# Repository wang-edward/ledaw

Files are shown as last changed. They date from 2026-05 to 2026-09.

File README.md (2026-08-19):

# ledaw

run desktop app
```sh
cargo run
```

build
```sh
cargo build
```

build firmware
```sh
cargo build -p firmware
```

test
```sh
cargo test
```

lint + format
```sh
# rustup component add clippy rustfmt  # if you don't have it
cargo clippy --all-targets --all-features
cargo fmt --check
```

## Firmware

see [`firmware/README.md`](firmware/README.md) for flashing the rp2350.

## pics
Screenshot 2026-03-18 at 12 51 28 AM
Screenshot 2026-03-18 at 12 51 50 AM
Screenshot 2026-03-18 at 12 52 29 AM

## Video demo
video demo (https://www.youtube.com/watch?v=XMdhAa6qCPk)

## Video demo 2 (art project)
art demo (https://www.youtube.com/watch?v=T37_Ot39h1g)

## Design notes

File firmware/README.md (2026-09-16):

## Prerequisites
Install the embedded Rust target:
```sh
rustup target add thumbv8m.main-none-eabihf
```

Install [cargo-embed](https://probe.rs/docs/tools/cargo-embed/):
```sh
cargo install cargo-embed
```

Load the Raspberry Pi Debug Probe firmware onto the RP2040. (MacOS)
```sh
cp probe/debugprobe_on_pico.uf2 /Volumes/RPI-RP2/
```

Connect the RP2040 to the computer over USB and connect its SWD pins to the RP2350:
```text
RP2040 GP2 -> RP2350 SWCLK
RP2040 GP3 -> RP2350 SWDIO
RP2040 GND -> carrier GND
```

## Build
Run this from the `firmware` directory so Cargo loads its embedded target and runner configuration:
```sh
cargo build
```

Flash And Run Over SWD
```sh
cargo embed
```

Check Probe Connection
```sh
probe-rs list
probe-rs info --chip RP235x --protocol swd
```

Examples
```
cargo embed --example uart_echo
cargo embed --example midi_loopback
cargo joystick
```

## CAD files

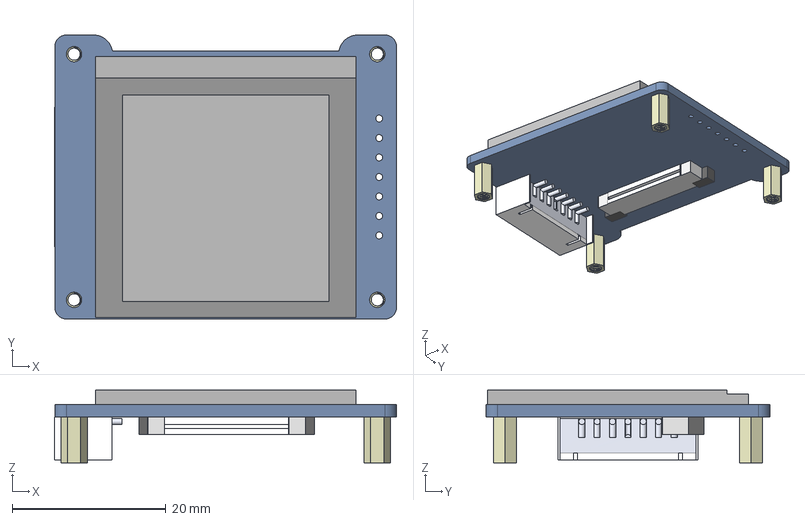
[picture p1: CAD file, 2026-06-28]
hardware/board/3d/1_5inch-rgb-oled-module_asm-1110.stp
44.5 x 37.0 x 9.50 mm
1_5INCH-RGB-OLED
1_5INCH_OLED_RGB_PCBA
M2XH6_COPPER-POST x 4

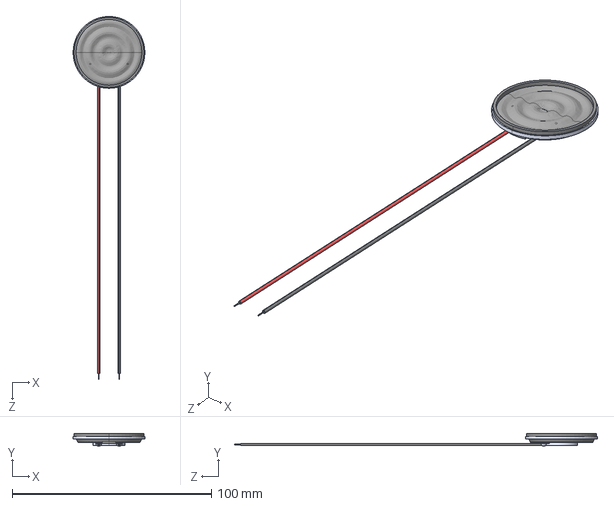
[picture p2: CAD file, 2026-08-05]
hardware/board/3d/Same_Sky_CLS0361-L152.step
36.0 x 6.30 x 182.0 mm

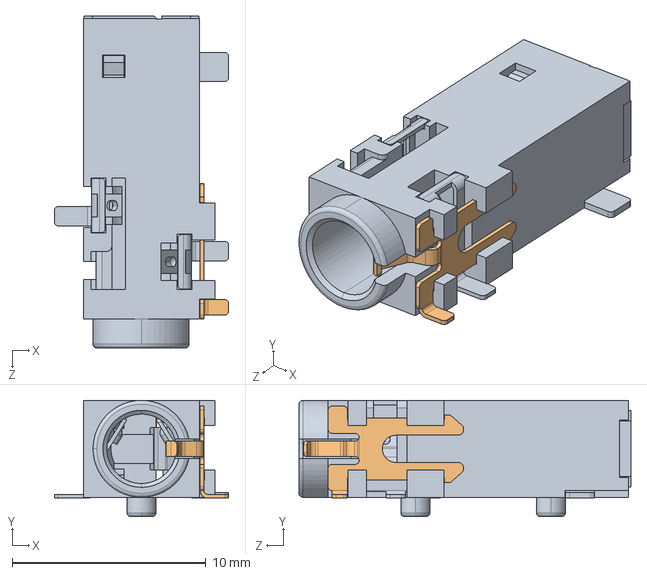
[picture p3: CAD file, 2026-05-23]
hardware/hat/3d/SJ-43514-SMT-TR.step
9.00 x 6.00 x 17.1 mm

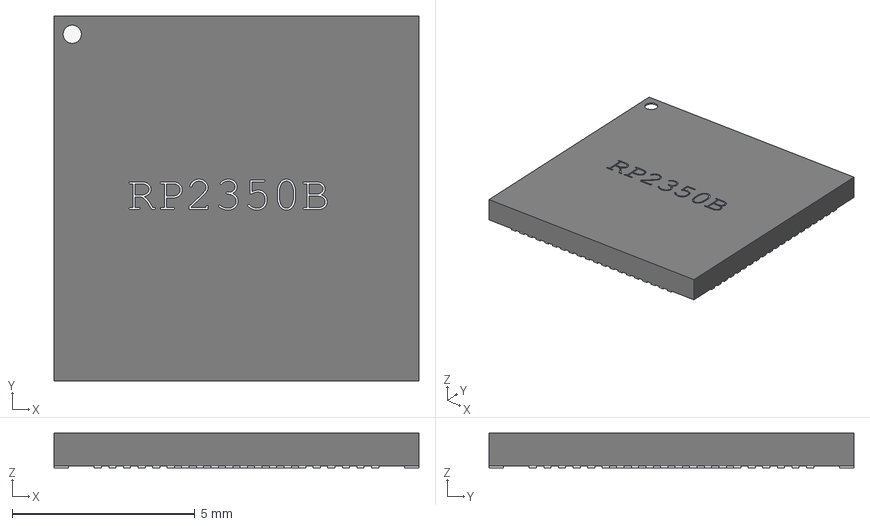
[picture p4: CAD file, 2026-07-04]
hardware/RP2350_80QFN_minimal/RP2350_QFN80.step
10.0 x 10.0 x 0.95 mm

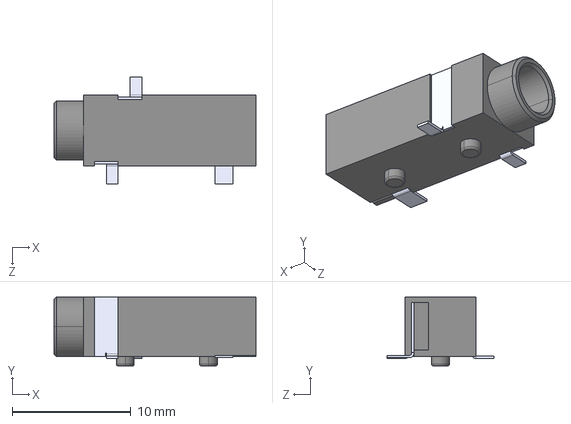
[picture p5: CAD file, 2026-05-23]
hardware/hat/3d/SJ-3523-SMT-TR.step
17.0 x 5.80 x 9.00 mm

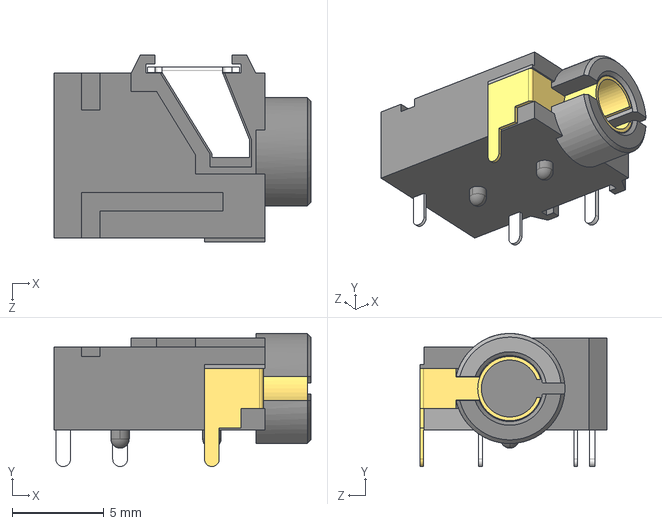
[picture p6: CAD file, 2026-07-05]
hardware/board/3d/SJ-43514.step
14.0 x 7.25 x 10.2 mm

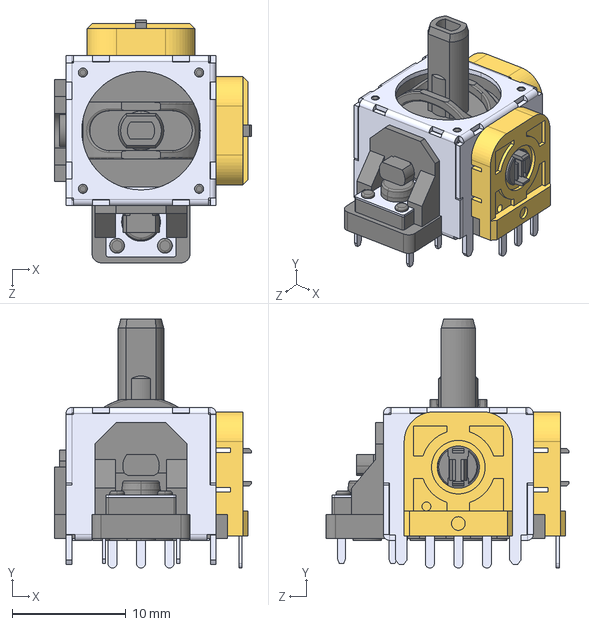
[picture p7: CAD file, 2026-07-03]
hardware/board/3d/THB001P.STEP
17.3 x 21.9 x 21.3 mm

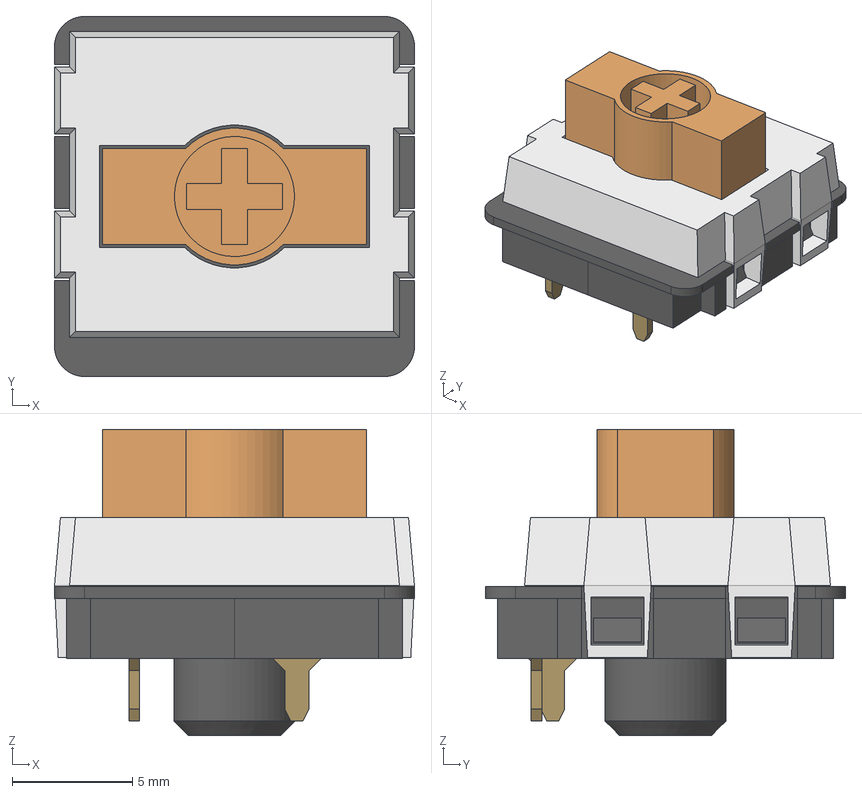
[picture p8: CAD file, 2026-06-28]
hardware/board/3d/Gateron KS-33.step
15.0 x 15.0 x 12.8 mm
Base
Stem
Cap
PinA
PinB

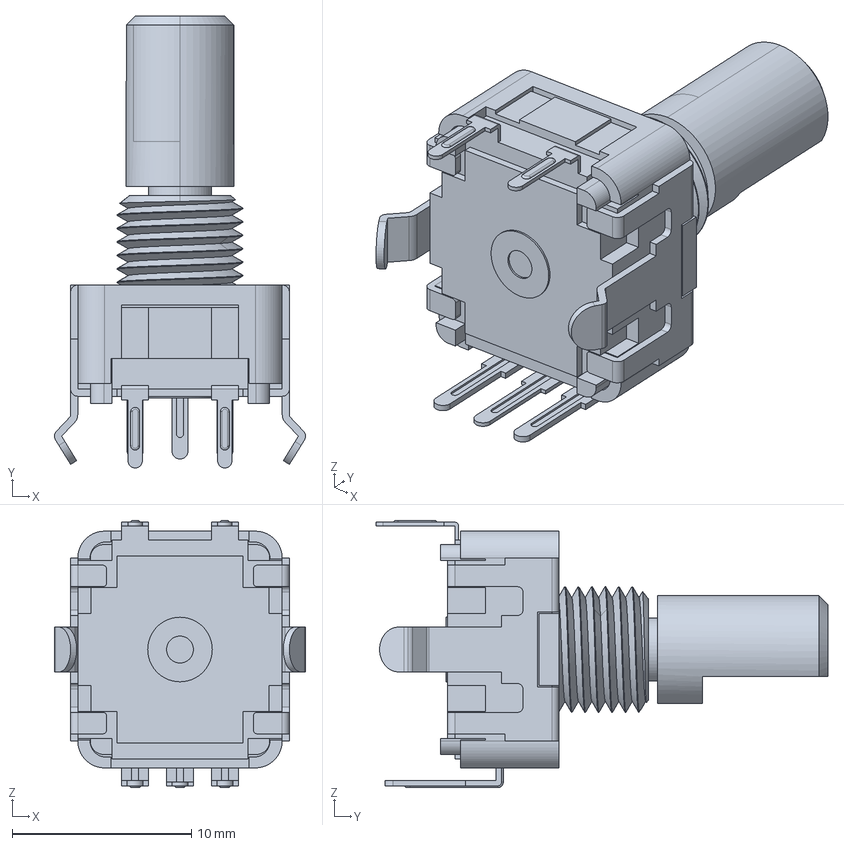
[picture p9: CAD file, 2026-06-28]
hardware/board/3d/pec11r-4015f-s0024.stp
14.0 x 25.2 x 14.9 mm

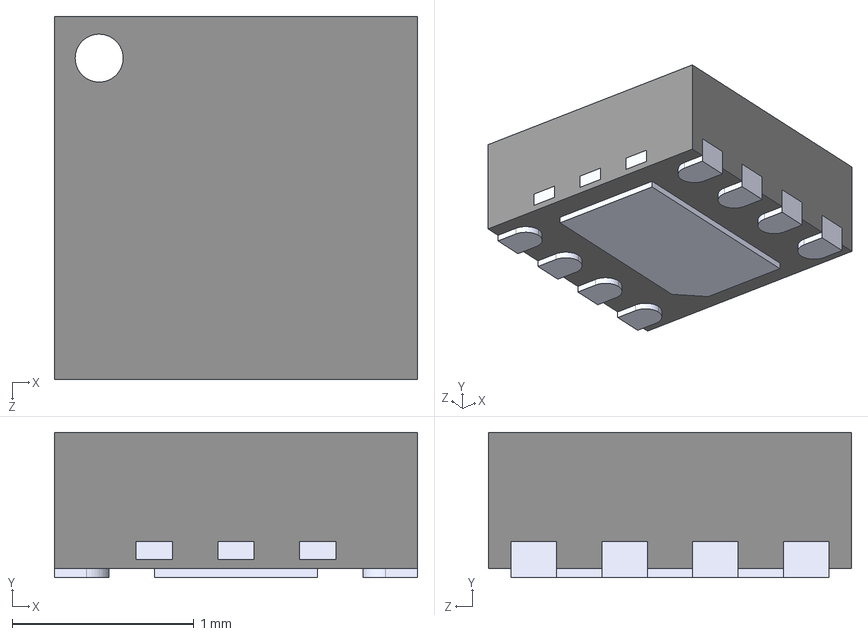
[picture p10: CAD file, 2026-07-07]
hardware/board/3d/TPS259531DSGR.step
2.00 x 0.8 x 2.00 mm

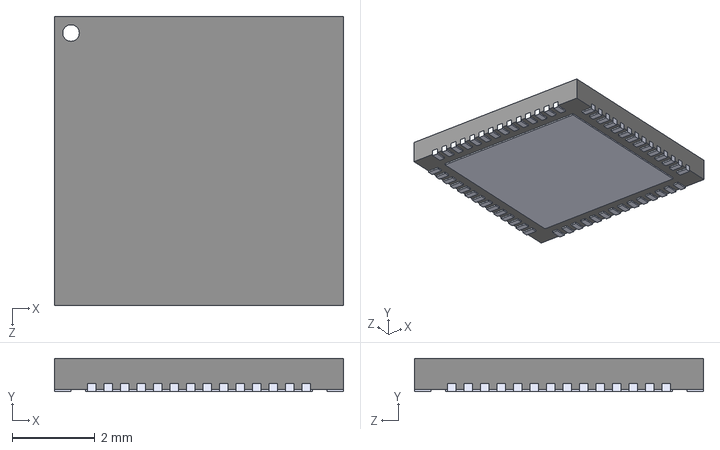
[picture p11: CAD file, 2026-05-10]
hardware/hat/3d/MAX98089ETN_T.step
7.00 x 0.8 x 7.00 mm

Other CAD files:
hardware/board/3d/Same_Sky_CLS0361-L152.x_t

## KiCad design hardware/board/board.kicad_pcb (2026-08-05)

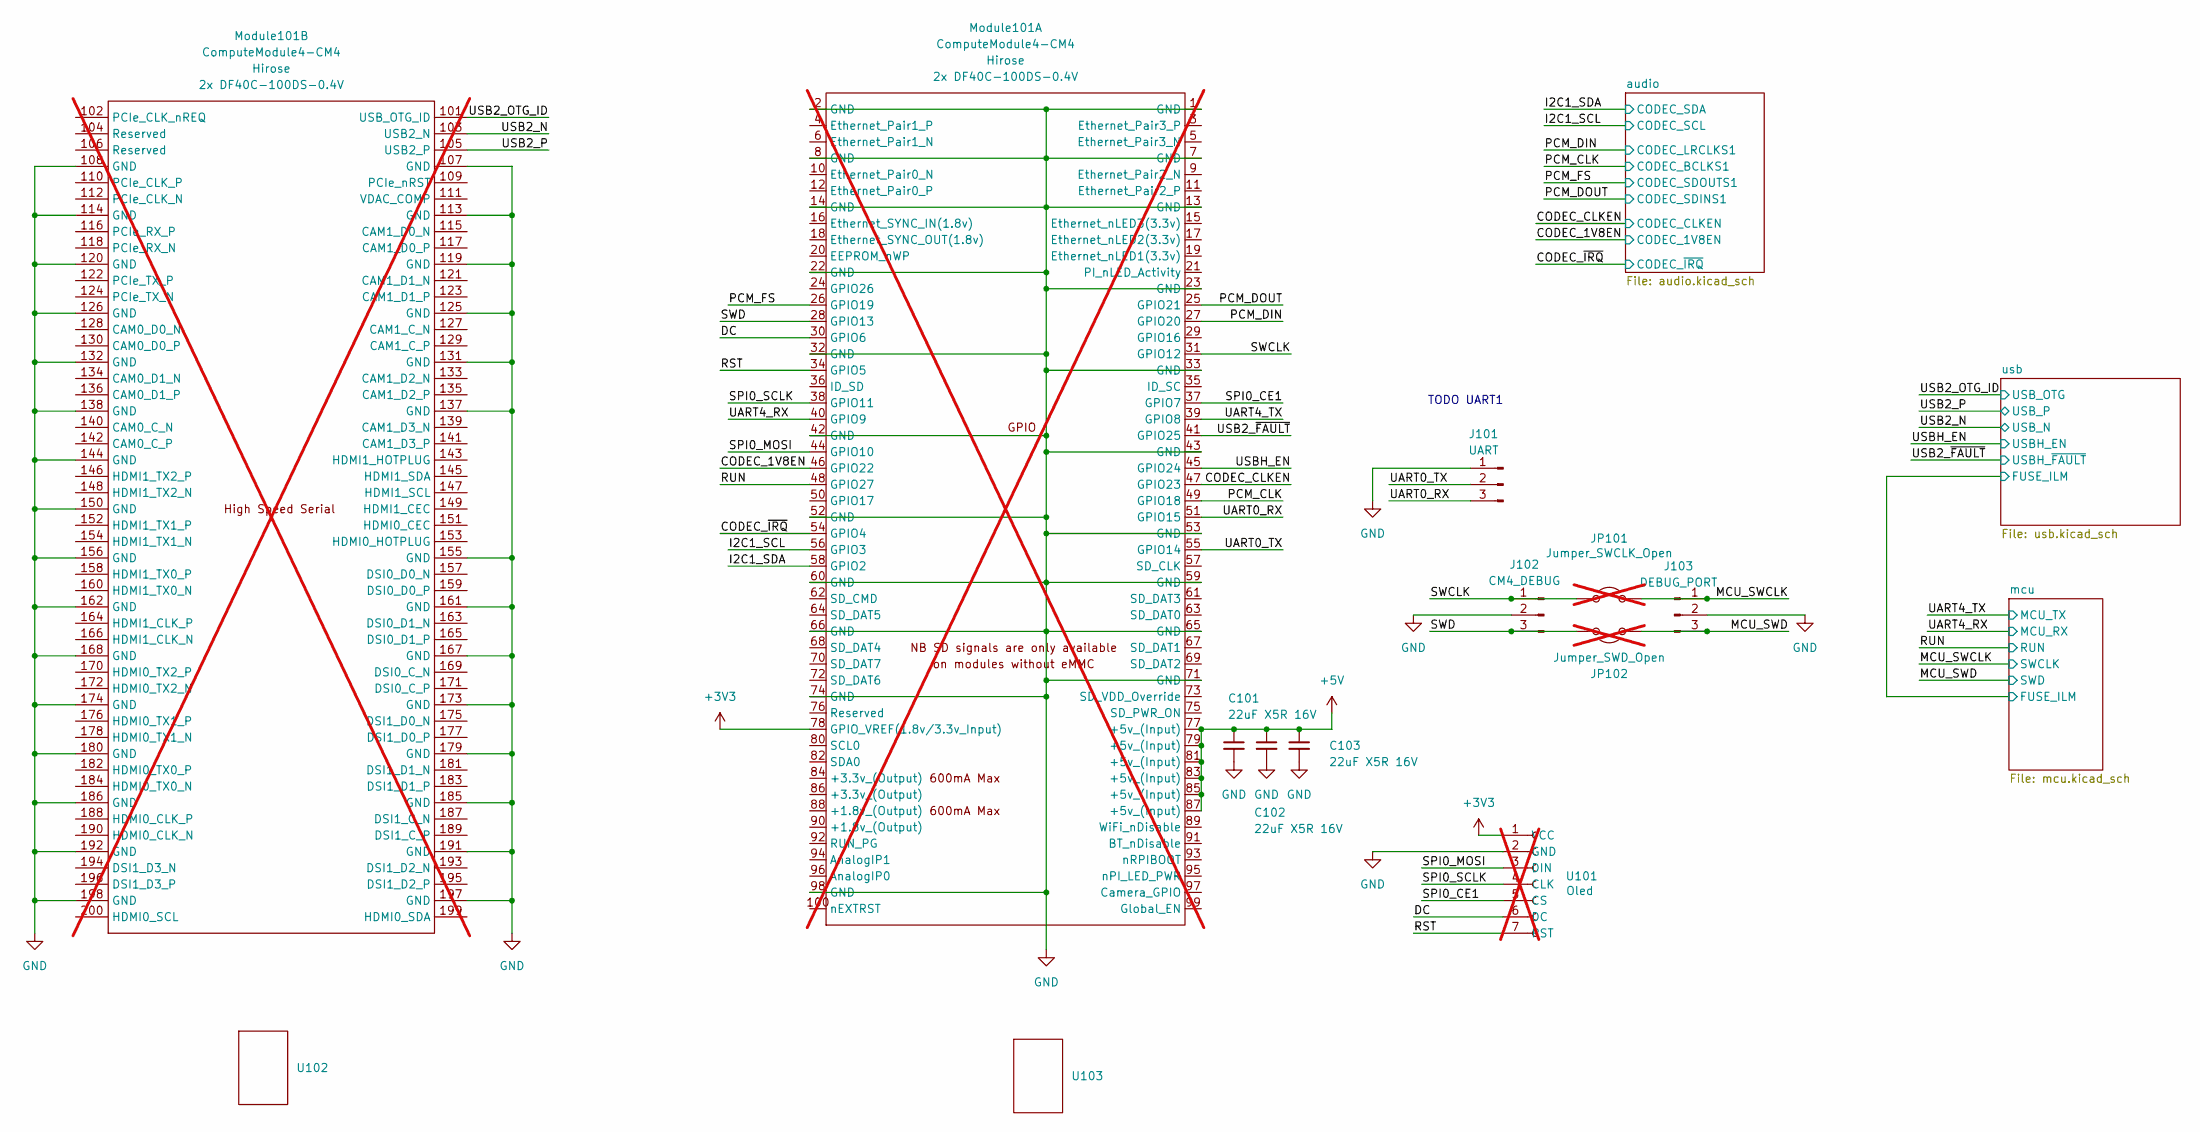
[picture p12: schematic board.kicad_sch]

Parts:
C101, C102, C103: 22uF X5R 16V; C_1206_3216Metric; LCSC C90146
J101: UART; PinSocket_1x03_P2.54mm_Vertical; LCSC C52016391
J102: CM4_DEBUG; PinSocket_1x03_P2.54mm_Vertical; LCSC C52016391
J103: DEBUG_PORT; PinSocket_1x03_P2.54mm_Vertical; LCSC C52016391
JP101: Jumper_SWCLK_Open; SolderJumper-2_P1.3mm_Open_TrianglePad1.0x1.5mm; not fitted
JP102: Jumper_SWD_Open; SolderJumper-2_P1.3mm_Open_TrianglePad1.0x1.5mm; not fitted
Module101: ComputeModule4-CM4; Raspberry-Pi-4-Compute-Module; not fitted
U101: Oled; waveshare-1.5inch-oled; not fitted
U102, U103: Hirose_DF40C-100DS-0.4V_2x50_P0.4mm; LCSC C597931

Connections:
+3V3: Module101.78 (GPIO_VREF(1.8v/3.3v_Input)), U101.1 (VCC); also elsewhere on the board
+5V: C101.1, C102.1, C103.1, Module101.77 (+5v_(Input)), Module101.79 (+5v_(Input)), Module101.81 (+5v_(Input)), Module101.83 (+5v_(Input)), Module101.85 (+5v_(Input)), Module101.87 (+5v_(Input)); also elsewhere on the board
/CODEC_1V8EN: Module101.46 (GPIO22); also elsewhere on the board
/CODEC_CLKEN: Module101.47 (GPIO23); also elsewhere on the board
/CODEC_~IRQ: Module101.54 (GPIO4); also elsewhere on the board
/DC: Module101.30 (GPIO6), U101.6 (DC)
/I2C1_SCL: Module101.56 (GPIO3); also elsewhere on the board
/I2C1_SDA: Module101.58 (GPIO2); also elsewhere on the board
/MCU_SWCLK: J103.1, JP101.2 (B); also elsewhere on the board
/MCU_SWD: J103.3, JP102.2 (B); also elsewhere on the board
/PCM_CLK: Module101.49 (GPIO18); also elsewhere on the board
/PCM_DIN: Module101.27 (GPIO20); also elsewhere on the board
/PCM_DOUT: Module101.25 (GPIO21); also elsewhere on the board
/PCM_FS: Module101.26 (GPIO19); also elsewhere on the board
/RST: Module101.34 (GPIO5), U101.7 (RST)
/RUN: Module101.48 (GPIO27); also elsewhere on the board
/SPI0_CE1: Module101.37 (GPIO7), U101.5 (CS)
/SPI0_MOSI: Module101.44 (GPIO10), U101.3 (DIN)
/SPI0_SCLK: Module101.38 (GPIO11), U101.4 (CLK)
/SWCLK: J102.1, JP101.1 (A), Module101.31 (GPIO12)
/SWD: J102.3, JP102.1 (A), Module101.28 (GPIO13)
/UART0_RX: J101.3, Module101.51 (GPIO15)
/UART0_TX: J101.2, Module101.55 (GPIO14)
/UART4_RX: Module101.40 (GPIO9); also elsewhere on the board
/UART4_TX: Module101.39 (GPIO8); also elsewhere on the board
/USB2_N: Module101.103 (USB2_N); also elsewhere on the board
/USB2_OTG_ID: Module101.101 (USB_OTG_ID); also elsewhere on the board
/USB2_P: Module101.105 (USB2_P); also elsewhere on the board
/USB2_~FAULT: Module101.41 (GPIO25); also elsewhere on the board
/USBH_EN: Module101.45 (GPIO24); also elsewhere on the board
GND: C101.2, C102.2, C103.2, J101.1, J102.2, J103.2, Module101.1 (GND), Module101.2 (GND), Module101.7 (GND), Module101.8 (GND), Module101.13 (GND), Module101.14 (GND), Module101.22 (GND), Module101.23 (GND), Module101.32 (GND), Module101.33 (GND), Module101.42 (GND), Module101.43 (GND), Module101.52 (GND), Module101.53 (GND), Module101.59 (GND), Module101.60 (GND), Module101.65 (GND), Module101.66 (GND), Module101.71 (GND), Module101.74 (GND), Module101.98 (GND), Module101.107 (GND), Module101.108 (GND), Module101.113 (GND), Module101.114 (GND), Module101.119 (GND), Module101.120 (GND), Module101.125 (GND), Module101.126 (GND), Module101.131 (GND), Module101.132 (GND), Module101.137 (GND), Module101.138 (GND), Module101.144 (GND), Module101.150 (GND), Module101.155 (GND), Module101.156 (GND), Module101.161 (GND), Module101.162 (GND), Module101.167 (GND), Module101.168 (GND), Module101.173 (GND), Module101.174 (GND), Module101.179 (GND), Module101.180 (GND), Module101.185 (GND), Module101.186 (GND), Module101.191 (GND), Module101.192 (GND), Module101.197 (GND), Module101.198 (GND), U101.2 (GND); also elsewhere on the board

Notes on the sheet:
TODO UART1

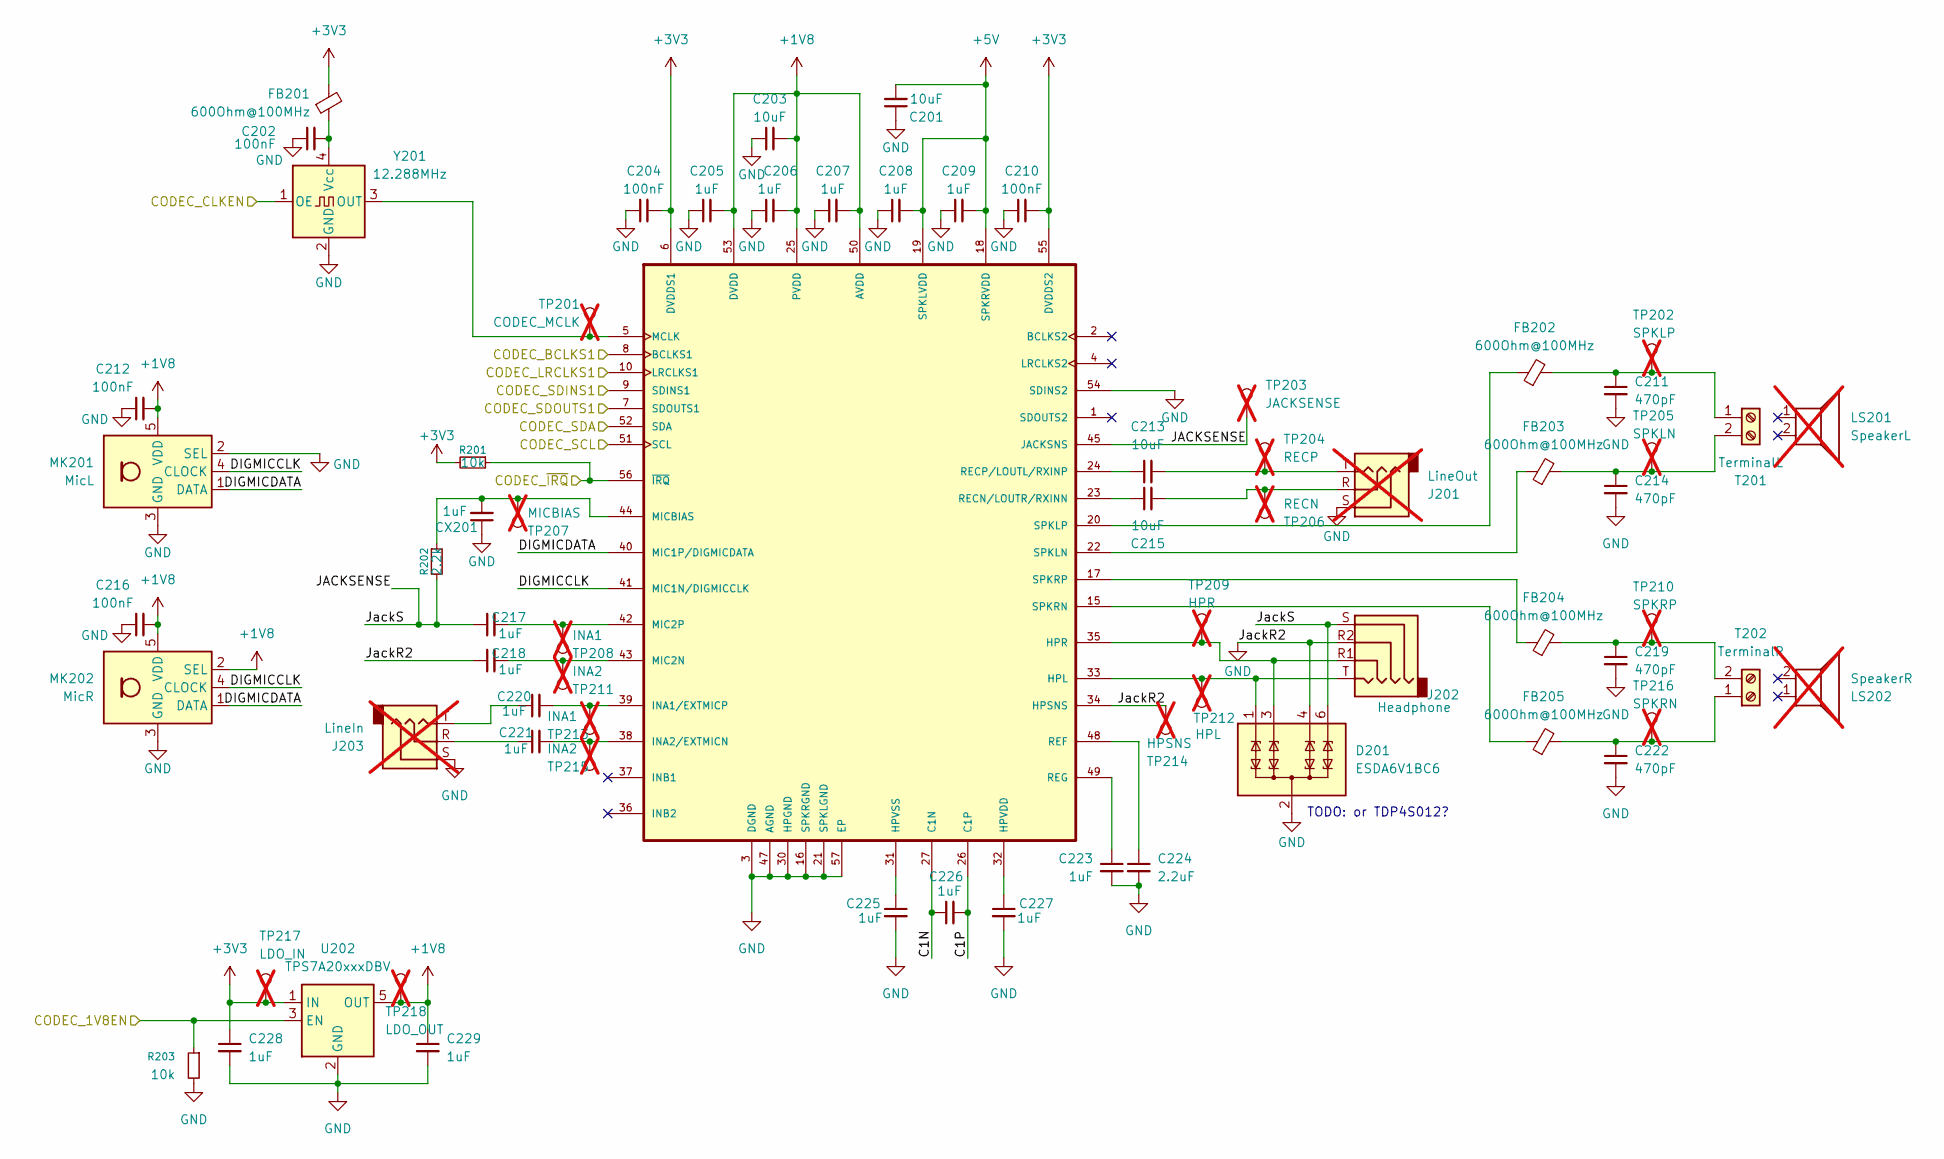
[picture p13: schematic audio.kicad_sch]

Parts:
C201, C203, C213, C215: 10uF; C_0805_2012Metric; LCSC C1713
C202, C204, C210, C212, C216: 100nF; C_0805_2012Metric; LCSC C49678
C205, C206, C207, C208, C209, C217, C218, C220, C221, C223, C225, C226, C227, C228, C229: 1uF; C_0805_2012Metric; LCSC C28323
C211, C214, C219, C222: 470pF; C_0805_2012Metric; LCSC C1743
C224: 2.2uF; C_0805_2012Metric; LCSC C377773
CX201: 1uF; C_0805_2012Metric; LCSC C28323
D201: ESDA6V1BC6; SOT-23-6; LCSC C495220
FB201, FB202, FB203, FB204, FB205: 600Ohm@100MHz; L_0805_2012Metric; LCSC C341663
J201: LineOut; Jack_3.5mm_CUI_SJ1-3525N_Horizontal; not fitted
J202: Headphone; CUI_SJ-43514; LCSC C20182909
J203: LineIn; Jack_3.5mm_CUI_SJ1-3525N_Horizontal; not fitted
LS201: SpeakerL; bf-32-s-8ohm; LCSC C474881; not fitted
LS202: SpeakerR; bf-32-s-8ohm; LCSC C474881; not fitted
MK201: MicL; Knowles_LGA-5_3.5x2.65mm; LCSC C2879853
MK202: MicR; Knowles_LGA-5_3.5x2.65mm; LCSC C2879853
R201, R203: 10k; R_0805_2012Metric; LCSC C17414
R202: 2.2k; R_0805_2012Metric; LCSC C17520
T201: TerminalL; TerminalBlock_Phoenix_MKDS-1,5-2-5.08_1x02_P5.08mm_Horizont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; LCSC C5183929
T202: TerminalR; TerminalBlock_Phoenix_MKDS-1,5-2-5.08_1x02_P5.08mm_Horizont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; LCSC C5183929
TP201: CODEC_MCLK; TestPoint_Pad_D2.0mm; not fitted
TP202: SPKLP; TestPoint_Pad_D2.0mm; not fitted
TP203: JACKSENSE; TestPoint_Pad_D2.0mm; not fitted
TP204: RECP; TestPoint_Pad_D2.0mm; not fitted
TP205: SPKLN; TestPoint_Pad_D2.0mm; not fitted
TP206: RECN; TestPoint_Pad_D2.0mm; not fitted
TP207: MICBIAS; TestPoint_Pad_D2.0mm; not fitted
TP208, TP213: INA1; TestPoint_Pad_D2.0mm; not fitted
TP209: HPR; TestPoint_Pad_D2.0mm; not fitted
TP210: SPKRP; TestPoint_Pad_D2.0mm; not fitted
TP211, TP215: INA2; TestPoint_Pad_D2.0mm; not fitted
TP212: HPL; TestPoint_Pad_D2.0mm; not fitted
TP214: HPSNS; TestPoint_Pad_D2.0mm; not fitted
TP216: SPKRN; TestPoint_Pad_D2.0mm; not fitted
TP217: LDO_IN; TestPoint_Pad_D2.0mm; not fitted
TP218: LDO_OUT; TestPoint_Pad_D2.0mm; not fitted
U201: MAX98089ETN_T; LCSC C2651816
U202: TPS7A20xxxDBV; SOT-23-5; LCSC C2862740
Y201: 12.288MHz; Oscillator_SMD_SeikoEpson_SG210-4Pin_2.5x2.0mm; LCSC C20617595

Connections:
+1V8: C203.2, C205.2, C206.2, C207.2, C212.2, C216.2, C229.1, MK201.5 (VDD), MK202.2 (SEL), MK202.5 (VDD), TP218.1, U201.25 (PVDD), U201.50 (AVDD), U201.53 (DVDD), U202.5 (OUT)
+3V3: C204.2, C210.2, C228.1, FB201.2, R201.2, TP217.1, U201.6 (DVDDS1), U201.55 (DVDDS2), U202.1 (IN); also elsewhere on the board
+5V: C201.2, C208.2, C209.2, U201.18 (SPKRVDD), U201.19 (SPKLVDD); also elsewhere on the board
/CODEC_1V8EN: R203.1, U202.3 (EN); also elsewhere on the board
/CODEC_CLKEN: Y201.1 (OE); also elsewhere on the board
/CODEC_~IRQ: R201.1, U201.56 (~IRQ); also elsewhere on the board
/I2C1_SCL: U201.51 (SCL); also elsewhere on the board
/I2C1_SDA: U201.52 (SDA); also elsewhere on the board
/PCM_CLK: U201.8 (BCLKS1); also elsewhere on the board
/PCM_DIN: U201.10 (LRCLKS1); also elsewhere on the board
/PCM_DOUT: U201.9 (SDINS1); also elsewhere on the board
/PCM_FS: U201.7 (SDOUTS1); also elsewhere on the board
/audio/C1N: C226.1, U201.27 (C1N)
/audio/C1P: C226.2, U201.26 (C1P)
/audio/DIGMICCLK: MK201.4 (CLOCK), MK202.4 (CLOCK), U201.41 (MIC1N/DIGMICCLK)
/audio/DIGMICDATA: MK201.1 (DATA), MK202.1 (DATA), U201.40 (MIC1P/DIGMICDATA)
/audio/JACKSENSE: C217.1, D201.6 (TVS4), J202.S, R202.2, TP203.1, U201.45 (JACKSNS)
GND: C201.1, C202.1, C203.1, C204.1, C205.1, C206.1, C207.1, C208.1, C209.1, C210.1, C211.2, C212.1, C214.2, C216.1, C218.1, C219.2, C222.2, C223.2, C224.2, C225.2, C227.2, C228.2, C229.2, CX201.1, D201.2 (COM), D201.4 (TVS3), D201.5 (COM), J201.S, J202.R2, J203.S, MK201.2 (SEL), MK201.3 (GND), MK202.3 (GND), R203.2, TP214.1, U201.3 (DGND), U201.16 (SPKRGND), U201.21 (SPKLGND), U201.30 (HPGND), U201.34 (HPSNS), U201.47 (AGND), U201.54 (SDINS2), U201.57 (EP), U202.2 (GND), Y201.2 (GND); also elsewhere on the board
unnamed: C213.2, J201.T, TP204.1
unnamed: C215.2, J201.R, TP206.1
unnamed: C220.1, J203.T
unnamed: C221.1, J203.R
unnamed: D201.1 (TVS1), J202.T, TP212.1, U201.33 (HPL)
unnamed: D201.3 (TVS2), J202.R1, TP209.1, U201.35 (HPR)
unnamed: C211.1, FB202.2, T201.1, TP202.1
unnamed: C214.1, FB203.2, T201.2, TP205.1
unnamed: C222.1, FB205.2, T202.1, TP216.1
unnamed: C219.1, FB204.2, T202.2, TP210.1
unnamed: C227.1, U201.32 (HPVDD)
unnamed: C225.1, U201.31 (HPVSS)
unnamed: C220.2, TP213.1, U201.39 (INA1/EXTMICP)
unnamed: C221.2, TP215.1, U201.38 (INA2/EXTMICN)
unnamed: TP201.1, U201.5 (MCLK), Y201.3 (OUT)
unnamed: C218.2, TP211.1, U201.43 (MIC2N)
unnamed: C217.2, TP208.1, U201.42 (MIC2P)
unnamed: CX201.2, R202.1, TP207.1, U201.44 (MICBIAS)
unnamed: C215.1, U201.23 (RECN/LOUTR/RXINN)
unnamed: C213.1, U201.24 (RECP/LOUTL/RXINP)
unnamed: C224.1, U201.48 (REF)
unnamed: C223.1, U201.49 (REG)
unnamed: FB203.1, U201.22 (SPKLN)
unnamed: FB202.1, U201.20 (SPKLP)
unnamed: FB205.1, U201.15 (SPKRN)
unnamed: FB204.1, U201.17 (SPKRP)
unnamed: C202.2, FB201.1, Y201.4 (Vcc)

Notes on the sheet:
TODO: or TDP4S012?

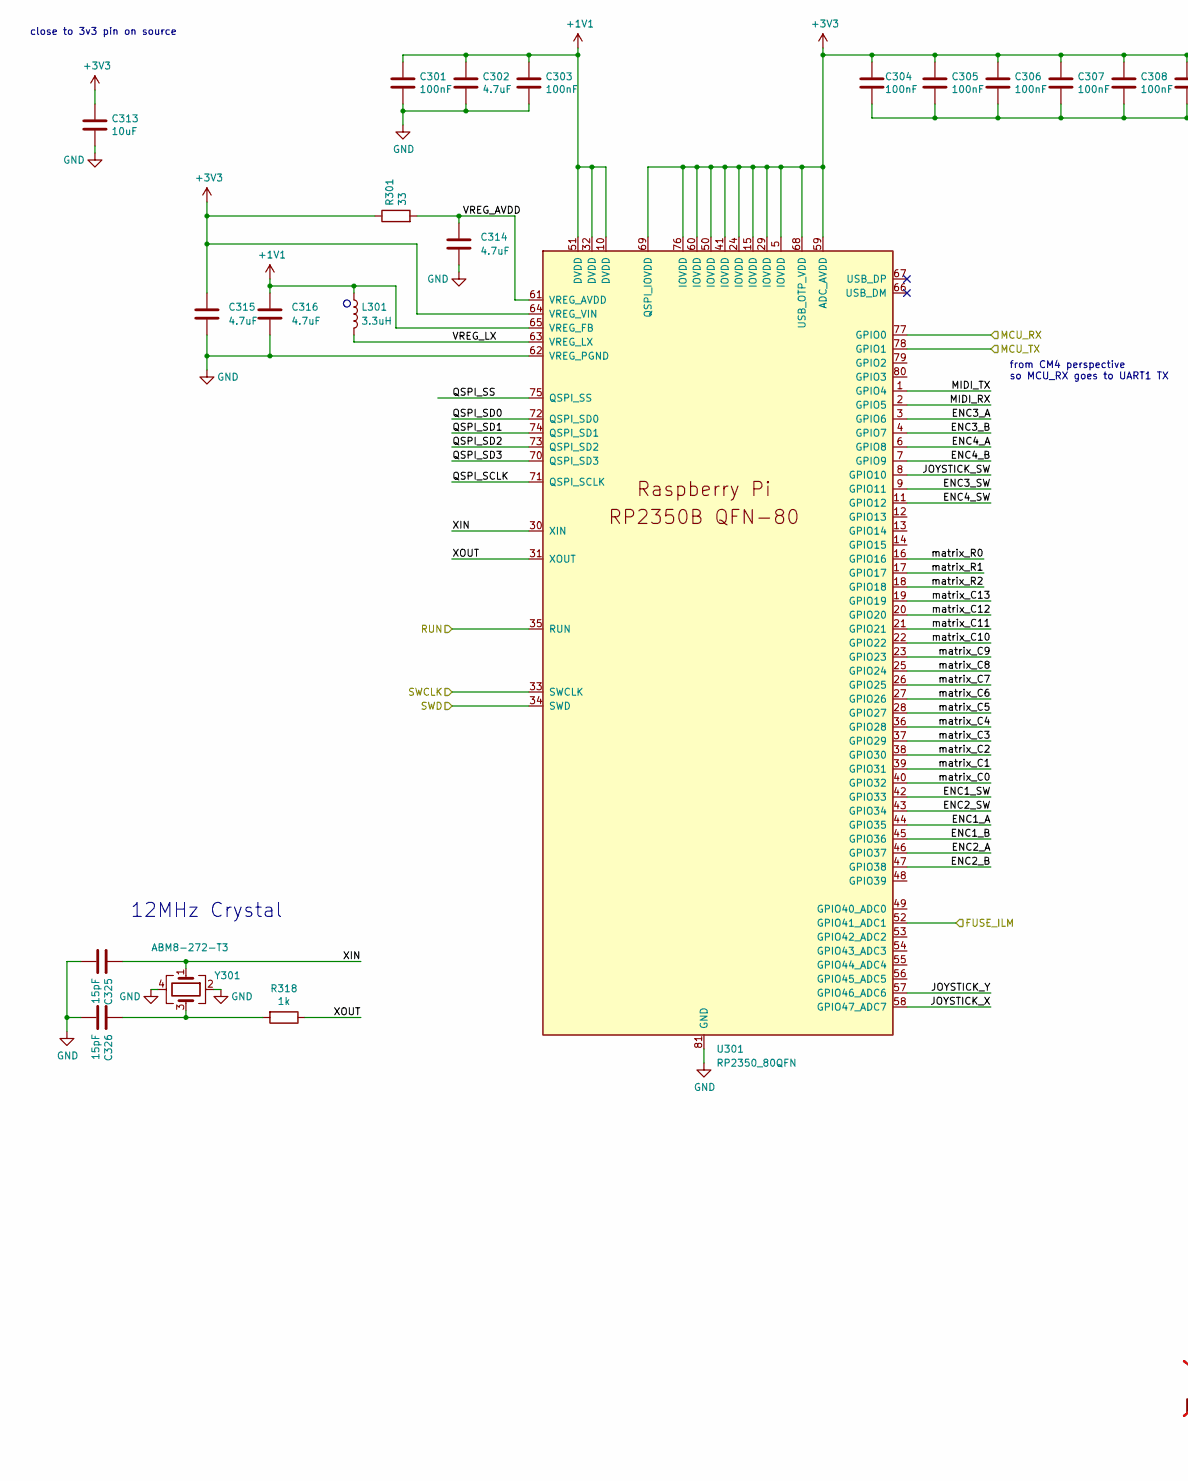
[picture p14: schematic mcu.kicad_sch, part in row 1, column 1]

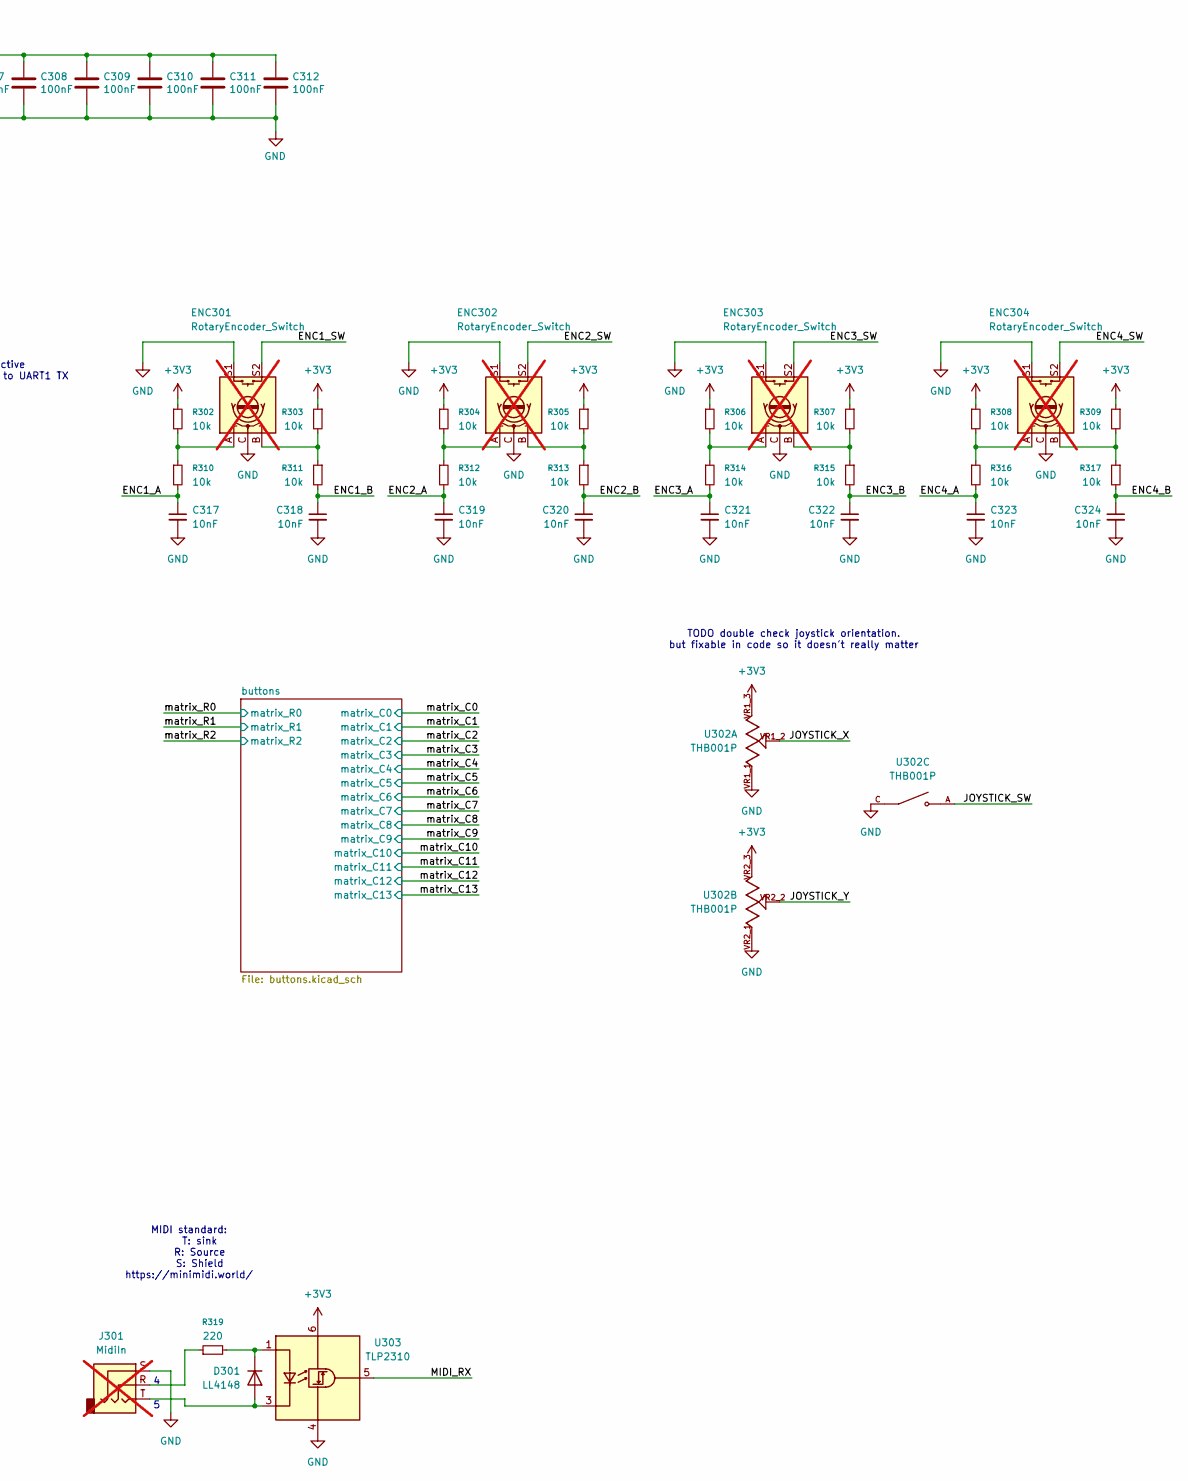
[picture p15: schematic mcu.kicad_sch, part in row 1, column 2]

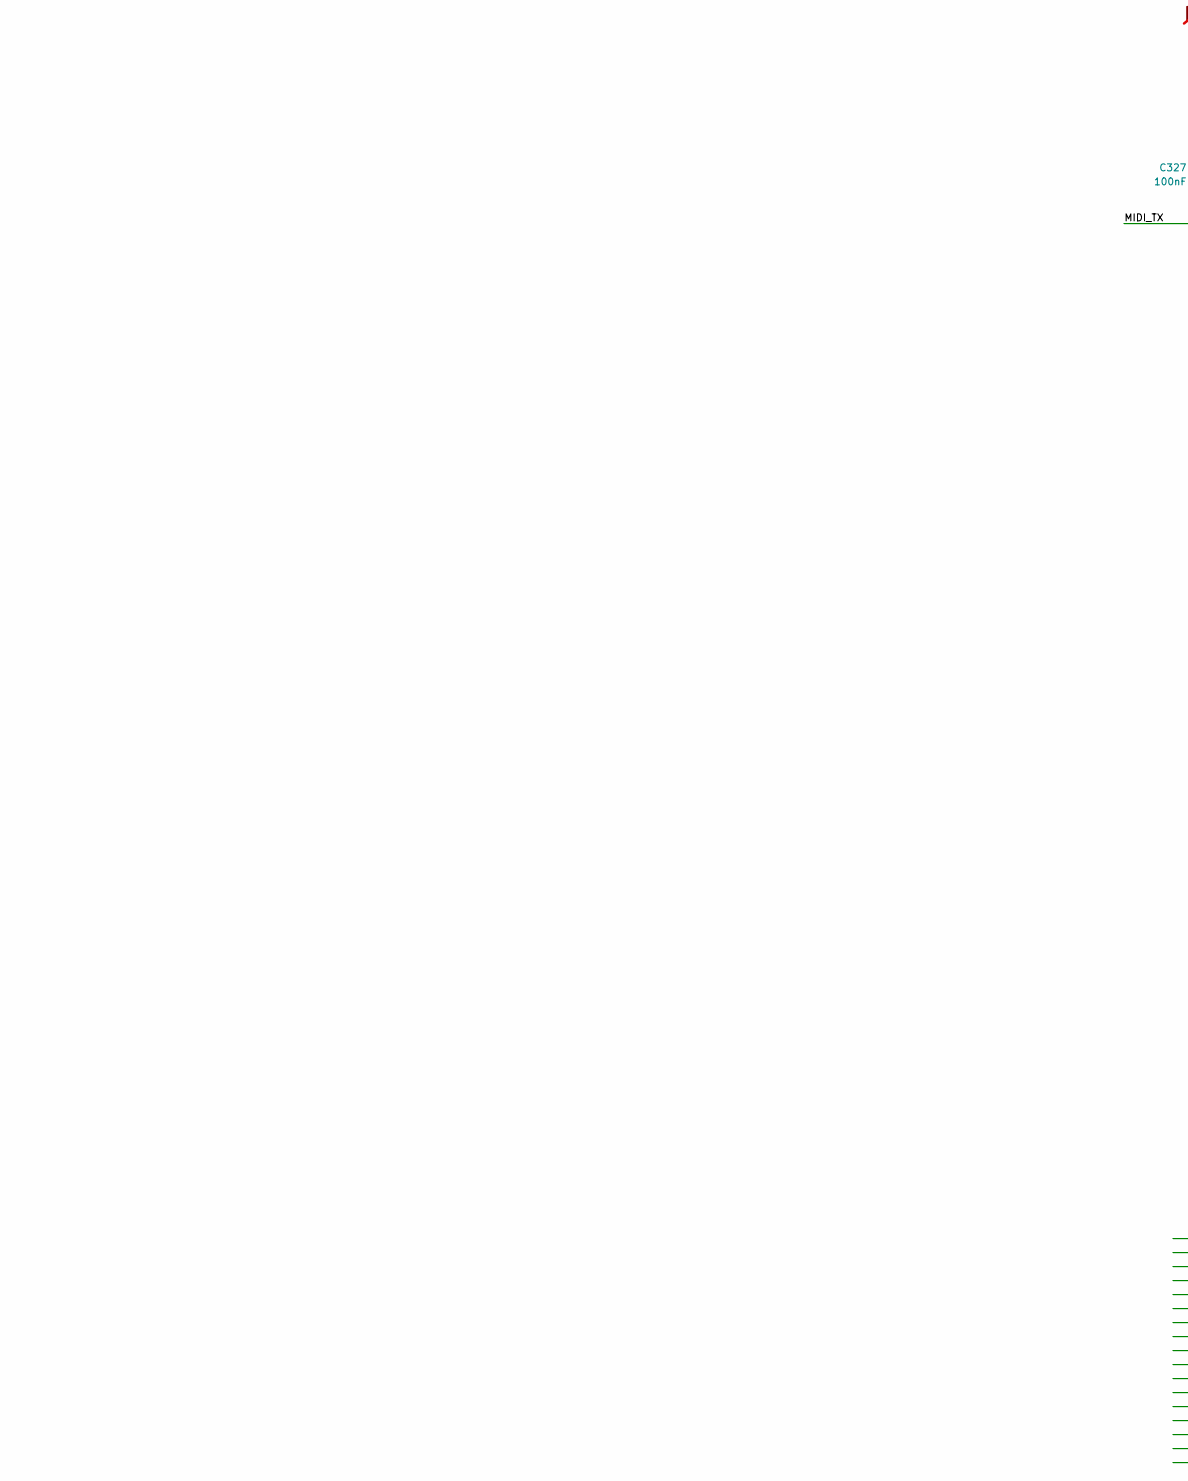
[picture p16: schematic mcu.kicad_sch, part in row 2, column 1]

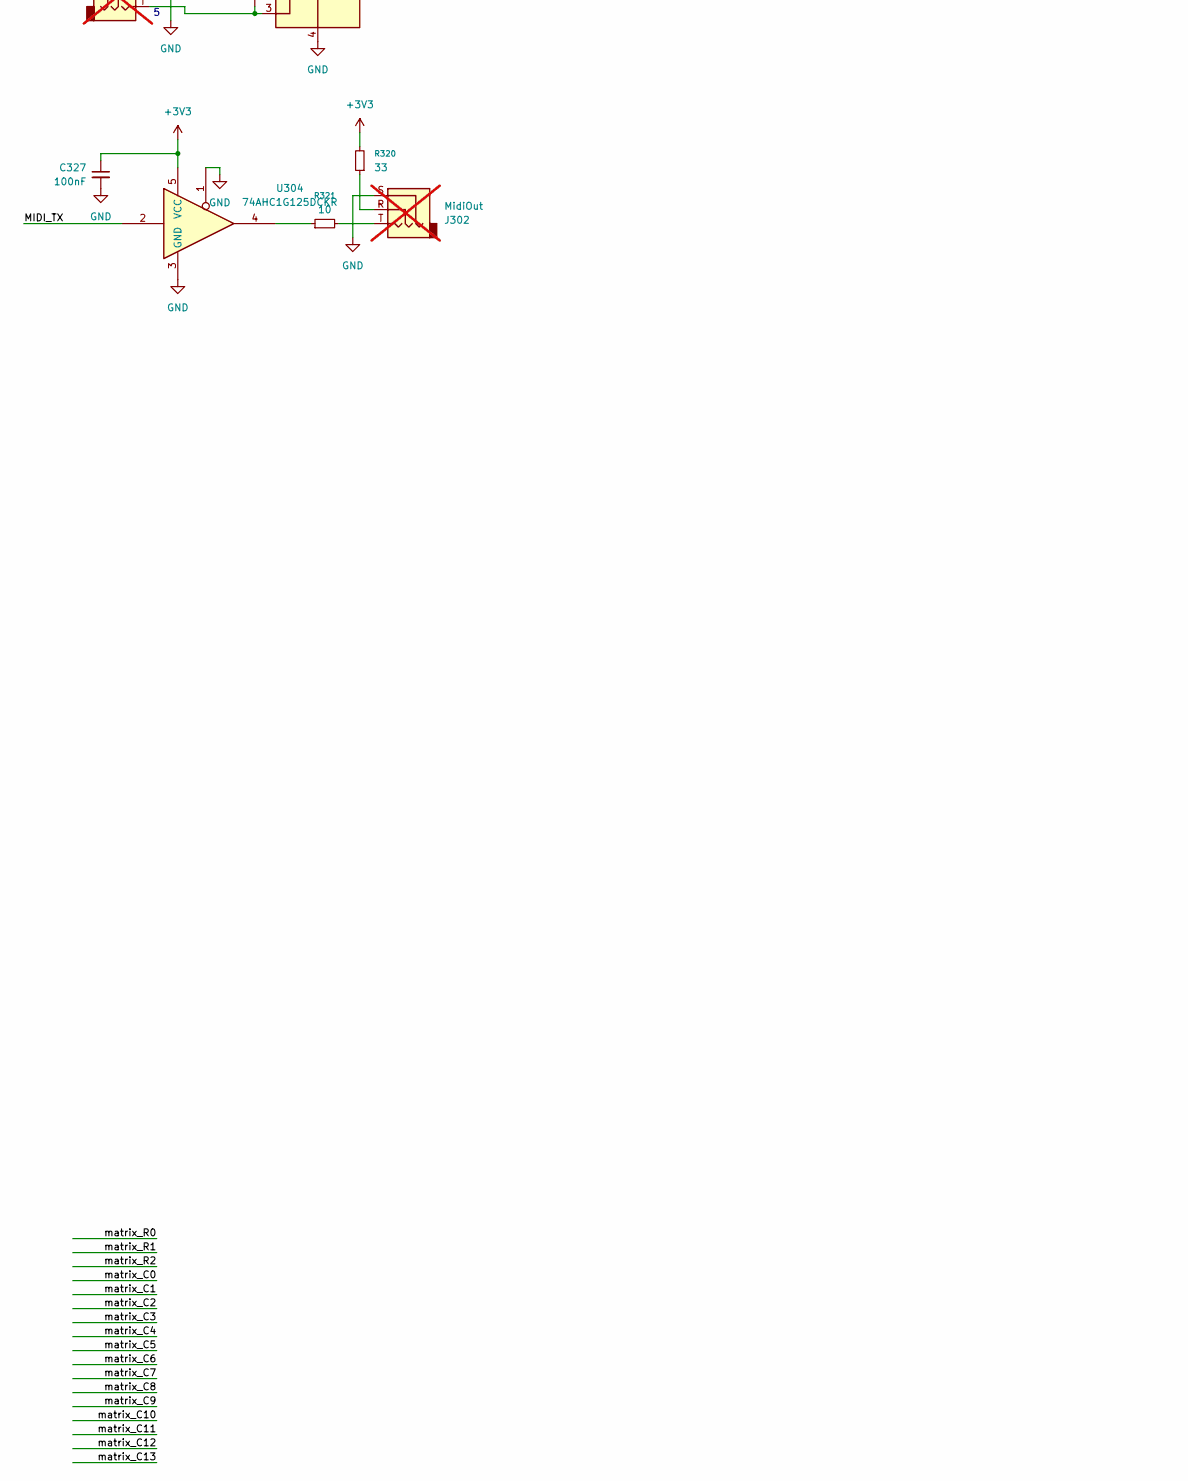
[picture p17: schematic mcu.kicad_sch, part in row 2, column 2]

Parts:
C301, C303, C304, C305, C306, C307, C308, C309, C310, C311, C312: 100nF; C_0402_1005Metric; LCSC C1525
C302, C314: 4.7uF; C_0402_1005Metric; LCSC C23733
C313: 10uF; C_0805_2012Metric; LCSC C1713
C315, C316: 4.7uF; C_0402_1005Metric_small_pads; LCSC C23733
C317, C318, C319, C320, C321, C322, C323, C324: 10nF; C_0805_2012Metric; LCSC C1710
C325, C326: 15pF; C_0402_1005Metric; LCSC C86285
C327: 100nF; C_0805_2012Metric; LCSC C49678
D301: LL4148; D_MiniMELF; LCSC C78608
ENC301, ENC302, ENC303, ENC304: RotaryEncoder_Switch; XDCR_PEC11R-4015F-S0024; not fitted
J301: MidiIn; Jack_3.5mm_CUI_SJ1-3525N_Horizontal; not fitted
J302: MidiOut; Jack_3.5mm_CUI_SJ1-3525N_Horizontal; not fitted
L301: 3.3uH; L_pol_2016; LCSC C42411119
R301: 33; R_0402_1005Metric; LCSC C25105
R302, R303, R304, R305, R306, R307, R308, R309, R310, R311, R312, R313, R314, R315, R316, R317: 10k; R_0805_2012Metric; LCSC C17414
R318: 1k; R_0402_1005Metric; LCSC C11702
R319: 220; R_0805_2012Metric; LCSC C17557
R320: 33; R_0805_2012Metric; LCSC C17634
R321: 10; R_0805_2012Metric; LCSC C17415
U301: RP2350_80QFN; RP2350-QFN-80-1EP_10x10_P0.4mm_EP3.4x3.4mm_ThermalVias; LCSC C39843328
U302: THB001P; PARTREV 27 Jan 22; LCSC C2685355
U303: TLP2310; SO-5-6_4.55x3.7mm_P1.27mm; LCSC C7473281
U304: 74AHC1G125DCKR; SOT-353_SC-70-5; LCSC C151890
Y301: ABM8-272-T3; Crystal_SMD_3225-4Pin_3.2x2.5mm; LCSC C20625731

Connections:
+1V1: C301.1, C302.1, C303.1, C316.1, L301.1, U301.10 (DVDD), U301.32 (DVDD), U301.51 (DVDD), U301.65 (VREG_FB)
+3V3: C304.1, C305.1, C306.1, C307.1, C308.1, C309.1, C310.1, C311.1, C312.1, C313.1, C315.1, C327.1, R301.1, R302.1, R303.1, R304.1, R305.1, R306.1, R307.1, R308.1, R309.1, R320.2, U301.5 (IOVDD), U301.15 (IOVDD), U301.24 (IOVDD), U301.29 (IOVDD), U301.41 (IOVDD), U301.50 (IOVDD), U301.59 (ADC_AVDD), U301.60 (IOVDD), U301.64 (VREG_VIN), U301.68 (USB_OTP_VDD), U301.69 (QSPI_IOVDD), U301.76 (IOVDD), U302.VR1_3, U302.VR2_3, U303.6 (VDD), U304.5 (VCC); also elsewhere on the board
/MCU_SWCLK: U301.33 (SWCLK); also elsewhere on the board
/MCU_SWD: U301.34 (SWD); also elsewhere on the board
/RUN: U301.35 (RUN); also elsewhere on the board
/UART4_RX: U301.77 (GPIO0); also elsewhere on the board
/UART4_TX: U301.78 (GPIO1); also elsewhere on the board
/mcu/ENC1_A: C317.1, R310.2, U301.44 (GPIO35)
/mcu/ENC1_B: C318.1, R311.2, U301.45 (GPIO36)
/mcu/ENC1_SW: ENC301.S2, U301.42 (GPIO33)
/mcu/ENC2_A: C319.1, R312.2, U301.46 (GPIO37)
/mcu/ENC2_B: C320.1, R313.2, U301.47 (GPIO38)
/mcu/ENC2_SW: ENC302.S2, U301.43 (GPIO34)
/mcu/ENC3_A: C321.1, R314.2, U301.3 (GPIO6)
/mcu/ENC3_B: C322.1, R315.2, U301.4 (GPIO7)
/mcu/ENC3_SW: ENC303.S2, U301.9 (GPIO11)
/mcu/ENC4_A: C323.1, R316.2, U301.6 (GPIO8)
/mcu/ENC4_B: C324.1, R317.2, U301.7 (GPIO9)
/mcu/ENC4_SW: ENC304.S2, U301.11 (GPIO12)
/mcu/FUSE_ILM: U301.52 (GPIO41_ADC1); also elsewhere on the board
/mcu/JOYSTICK_SW: U301.8 (GPIO10), U302.A, U302.B
/mcu/JOYSTICK_X: U301.58 (GPIO47_ADC7), U302.VR1_2
/mcu/JOYSTICK_Y: U301.57 (GPIO46_ADC6), U302.VR2_2
/mcu/MIDI_RX: U301.2 (GPIO5), U303.5 (VO)
/mcu/MIDI_TX: U301.1 (GPIO4), U304.2
/mcu/QSPI_SCLK: U301.71 (QSPI_SCLK)
/mcu/QSPI_SD0: U301.72 (QSPI_SD0)
/mcu/QSPI_SD1: U301.74 (QSPI_SD1)
/mcu/QSPI_SD2: U301.73 (QSPI_SD2)
/mcu/QSPI_SD3: U301.70 (QSPI_SD3)
/mcu/QSPI_SS: U301.75 (QSPI_SS)
/mcu/VREG_AVDD: C314.1, R301.2, U301.61 (VREG_AVDD)
/mcu/VREG_LX: L301.2, U301.63 (VREG_LX)
/mcu/XIN: C325.1, U301.30 (XIN), Y301.1
/mcu/XOUT: R318.1, U301.31 (XOUT)
/mcu/matrix_C0: U301.40 (GPIO32); also elsewhere on the board
/mcu/matrix_C1: U301.39 (GPIO31); also elsewhere on the board
/mcu/matrix_C2: U301.38 (GPIO30); also elsewhere on the board
/mcu/matrix_C3: U301.37 (GPIO29); also elsewhere on the board
/mcu/matrix_C4: U301.36 (GPIO28); also elsewhere on the board
/mcu/matrix_C5: U301.28 (GPIO27); also elsewhere on the board
/mcu/matrix_C6: U301.27 (GPIO26); also elsewhere on the board
/mcu/matrix_C7: U301.26 (GPIO25); also elsewhere on the board
/mcu/matrix_C8: U301.25 (GPIO24); also elsewhere on the board
/mcu/matrix_C9: U301.23 (GPIO23); also elsewhere on the board
/mcu/matrix_C10: U301.22 (GPIO22); also elsewhere on the board
/mcu/matrix_C11: U301.21 (GPIO21); also elsewhere on the board
/mcu/matrix_C12: U301.20 (GPIO20); also elsewhere on the board
/mcu/matrix_C13: U301.19 (GPIO19); also elsewhere on the board
/mcu/matrix_R0: U301.16 (GPIO16); also elsewhere on the board
/mcu/matrix_R1: U301.17 (GPIO17); also elsewhere on the board
/mcu/matrix_R2: U301.18 (GPIO18); also elsewhere on the board
GND: C301.2, C302.2, C303.2, C304.2, C305.2, C306.2, C307.2, C308.2, C309.2, C310.2, C311.2, C312.2, C313.2, C314.2, C315.2, C316.2, C317.2, C318.2, C319.2, C320.2, C321.2, C322.2, C323.2, C324.2, C325.2, C326.2, C327.2, ENC301.C, ENC301.S1, ENC302.C, ENC302.S1, ENC303.C, ENC303.S1, ENC304.C, ENC304.S1, J301.S, J302.S, U301.62 (VREG_PGND), U301.81 (GND), U302.C, U302.D, U302.VR1_1, U302.VR2_1, U303.4 (GND), U304.1, U304.3 (GND), Y301.2, Y301.4; also elsewhere on the board
unnamed: C326.1, R318.2, Y301.3
unnamed: D301.2 (A), J301.T, U303.3 (K)
unnamed: D301.1 (K), R319.2, U303.1 (A)
unnamed: ENC301.A, R302.2, R310.1
unnamed: ENC301.B, R303.2, R311.1
unnamed: ENC302.A, R304.2, R312.1
unnamed: ENC302.B, R305.2, R313.1
unnamed: ENC303.A, R306.2, R314.1
unnamed: ENC303.B, R307.2, R315.1
unnamed: ENC304.A, R308.2, R316.1
unnamed: ENC304.B, R309.2, R317.1
unnamed: J301.R, R319.1
unnamed: J302.R, R320.1
unnamed: J302.T, R321.2
unnamed: R321.1, U304.4

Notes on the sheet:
TODO double check joystick orientation. but fixable in code so it doesn't really matter
MIDI standard: T: sink R: Source S: Shield https://minimidi.world/
12MHz Crystal
close to 3v3 pin on source
from CM4 perspective so MCU_RX goes to UART1 TX

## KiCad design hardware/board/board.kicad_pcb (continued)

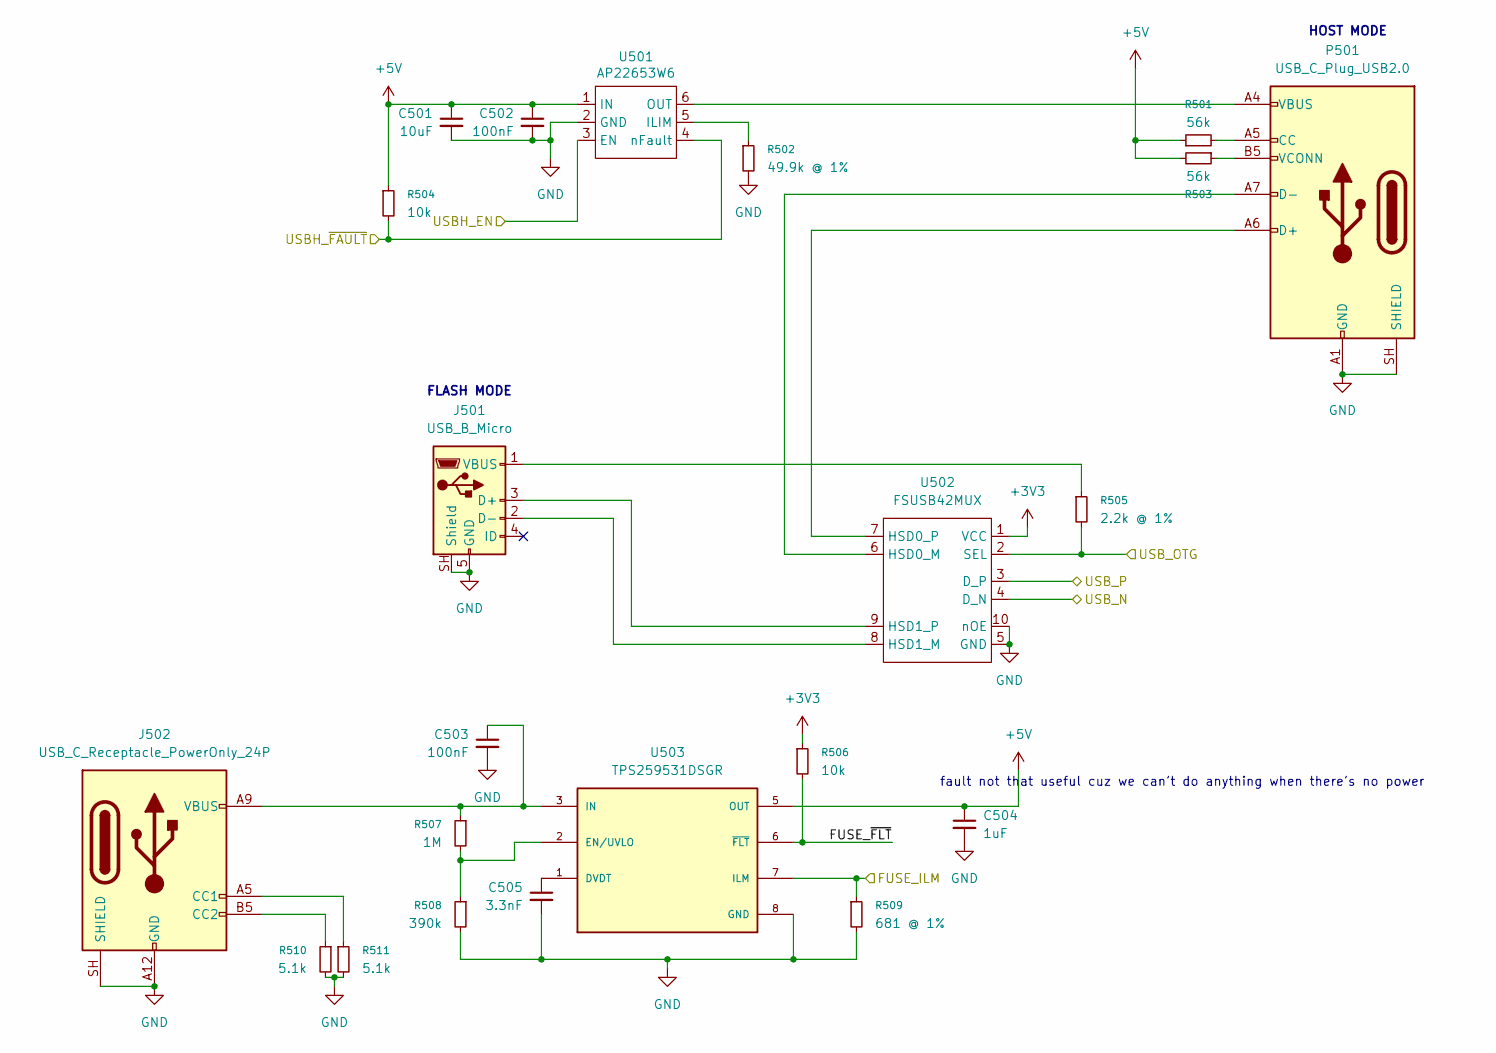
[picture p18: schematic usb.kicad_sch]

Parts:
C501: 10uF; C_0805_2012Metric; LCSC C1713
C502, C503: 100nF; C_0805_2012Metric; LCSC C49678
C504: 1uF; C_0805_2012Metric; LCSC C28323
C505: 3.3nF; C_0805_2012Metric; LCSC C1738
J501: USB_B_Micro; USB_Micro-B_Molex_47346-0001; LCSC C132560
J502: USB_C_Receptacle_PowerOnly_24P; USB_C_Receptacle_HRO_TYPE-C-31-M-12; LCSC C165948
P501: USB_C_Plug_USB2.0; USB_C_Receptacle_HRO_TYPE-C-31-M-12; LCSC C165948
R501, R503: 56k; R_0805_2012Metric; LCSC C17756
R502: 49.9k @ 1%; R_0805_2012Metric; LCSC C17719
R504, R506: 10k; R_0805_2012Metric; LCSC C17414
R505: 2.2k @ 1%; R_0805_2012Metric; LCSC C17520
R507: 1M; R_0805_2012Metric; LCSC C6351850
R508: 390k; R_0805_2012Metric; LCSC C17656
R509: 681 @ 1%; R_0805_2012Metric; LCSC C17800
R510, R511: 5.1k; R_0805_2012Metric; LCSC C26023
U501: AP22653W6; SOT-23-6; Part Description Power Switch/Driver 1:1 P-Channel 2.1A 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; LCSC C2158037
U502: FSUSB42MUX; MSOP-10_3x3mm_P0.5mm; LCSC C11355
U503: TPS259531DSGR; SON50P200X200X80-9N; PARTREV C; LCSC C2155674

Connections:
+3V3: R506.1, U502.1 (VCC); also elsewhere on the board
+5V: C501.1, C502.1, C504.1, R501.1, R503.2, R504.1, U501.1 (IN), U503.5 (OUT); also elsewhere on the board
/USB2_N: U502.4 (D_N); also elsewhere on the board
/USB2_OTG_ID: R505.2, U502.2 (SEL); also elsewhere on the board
/USB2_P: U502.3 (D_P); also elsewhere on the board
/USB2_~FAULT: R504.2, U501.4 (nFault); also elsewhere on the board
/USBH_EN: U501.3 (EN); also elsewhere on the board
/mcu/FUSE_ILM: R509.1, U503.7 (ILM); also elsewhere on the board
/usb/FUSE_~FLT: R506.2, U503.6 (~FLT)
GND: C501.2, C502.2, C503.2, C504.2, C505.2, J501.5 (GND), J501.SH (Shield), J502.A1 (GND), J502.A12 (GND), J502.B1 (GND), J502.B12 (GND), J502.SH (SHIELD), P501.A1 (GND), P501.A12 (GND), P501.B1 (GND), P501.B12 (GND), P501.SH (SHIELD), R502.2, R508.2, R509.2, R510.2, R511.2, U501.2 (GND), U502.5 (GND), U502.10 (nOE), U503.8 (GND), U503.9 (GND); also elsewhere on the board
unnamed: C503.1, J502.A4 (VBUS), J502.A9 (VBUS), J502.B4 (VBUS), J502.B9 (VBUS), R507.1, U503.3 (IN), U503.4 (IN)
unnamed: J501.3 (D+), U502.9 (HSD1_P)
unnamed: J501.2 (D-), U502.8 (HSD1_M)
unnamed: J501.1 (VBUS), R505.1
unnamed: J502.A5 (CC1), R511.1
unnamed: J502.B5 (CC2), R510.1
unnamed: P501.A5 (CC), R501.2
unnamed: P501.A6 (D+), U502.7 (HSD0_P)
unnamed: P501.A7 (D-), U502.6 (HSD0_M)
unnamed: P501.B5 (VCONN), R503.1
unnamed: R502.1, U501.5 (ILIM)
unnamed: P501.A4 (VBUS), P501.A9 (VBUS), P501.B4 (VBUS), P501.B9 (VBUS), U501.6 (OUT)
unnamed: C505.1, U503.1 (DVDT)
unnamed: R507.2, R508.1, U503.2 (EN/UVLO)

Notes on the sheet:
FLASH MODE
fault not that useful cuz we can't do anything when there's no power
HOST MODE

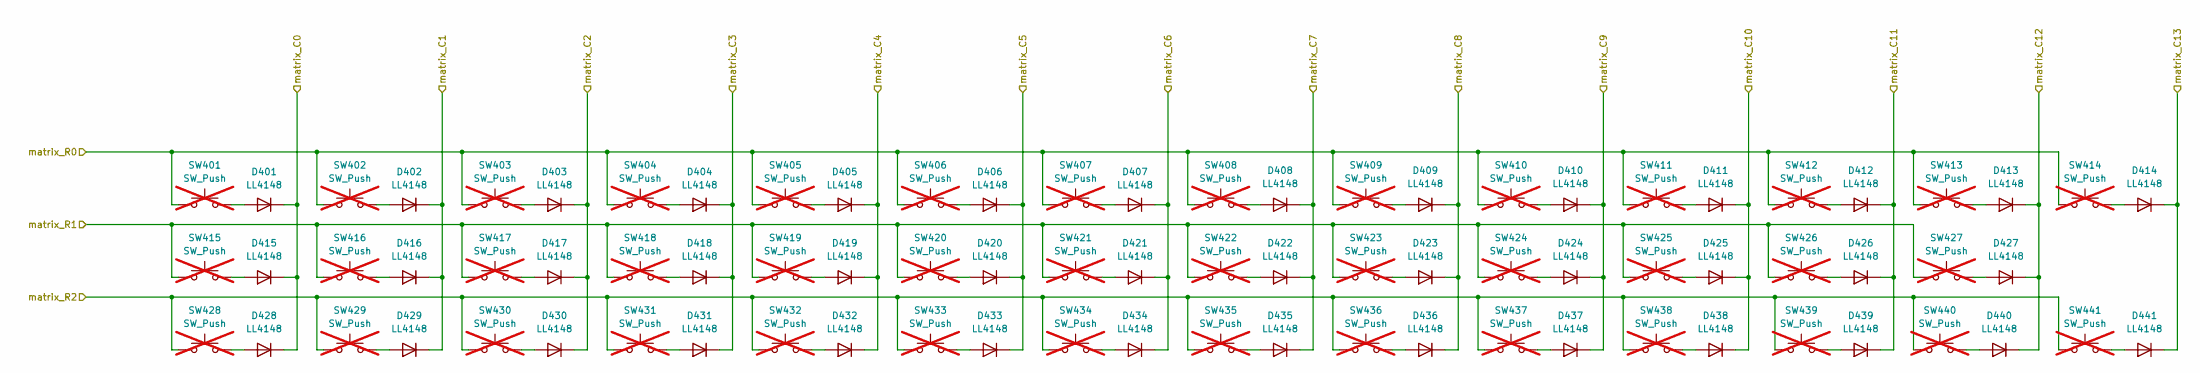
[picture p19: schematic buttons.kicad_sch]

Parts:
D401, D402, D403, D404, D405, D406, D407, D408, D409, D410, D411, D412, D413, D414, D415, D416, D417, D418, D419, D420, D421, D422, D423, D424, D425, D426, D427, D428, D429, D430, D431, D432, D433, D434, D435, D436, D437, D438, D439, D440, D441: LL4148; D_MiniMELF; LCSC C78608
SW401, SW402, SW403, SW404, SW405, SW406, SW407, SW408, SW409, SW410, SW411, SW412, SW413, SW414, SW415, SW416, SW417, SW418, SW419, SW420, SW421, SW422, SW423, SW424, SW425, SW426, SW427, SW428, SW429, SW430, SW431, SW432, SW433, SW434, SW435, SW436, SW437, SW438, SW439, SW440, SW441: SW_Push; ks-33-2.0; not fitted

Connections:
/mcu/matrix_C0: D401.1 (K), D415.1 (K), D428.1 (K); also elsewhere on the board
/mcu/matrix_C1: D402.1 (K), D416.1 (K), D429.1 (K); also elsewhere on the board
/mcu/matrix_C2: D403.1 (K), D417.1 (K), D430.1 (K); also elsewhere on the board
/mcu/matrix_C3: D404.1 (K), D418.1 (K), D431.1 (K); also elsewhere on the board
/mcu/matrix_C4: D405.1 (K), D419.1 (K), D432.1 (K); also elsewhere on the board
/mcu/matrix_C5: D406.1 (K), D420.1 (K), D433.1 (K); also elsewhere on the board
/mcu/matrix_C6: D407.1 (K), D421.1 (K), D434.1 (K); also elsewhere on the board
/mcu/matrix_C7: D408.1 (K), D422.1 (K), D435.1 (K); also elsewhere on the board
/mcu/matrix_C8: D409.1 (K), D423.1 (K), D436.1 (K); also elsewhere on the board
/mcu/matrix_C9: D410.1 (K), D424.1 (K), D437.1 (K); also elsewhere on the board
/mcu/matrix_C10: D411.1 (K), D425.1 (K), D438.1 (K); also elsewhere on the board
/mcu/matrix_C11: D412.1 (K), D426.1 (K), D439.1 (K); also elsewhere on the board
/mcu/matrix_C12: D413.1 (K), D427.1 (K), D440.1 (K); also elsewhere on the board
/mcu/matrix_C13: D414.1 (K), D441.1 (K); also elsewhere on the board
/mcu/matrix_R0: SW401.1, SW402.1, SW403.1, SW404.1, SW405.1, SW406.1, SW407.1, SW408.1, SW409.1, SW410.1, SW411.1, SW412.1, SW413.1, SW414.1; also elsewhere on the board
/mcu/matrix_R1: SW415.1, SW416.1, SW417.1, SW418.1, SW419.1, SW420.1, SW421.1, SW422.1, SW423.1, SW424.1, SW425.1, SW426.1, SW427.1; also elsewhere on the board
/mcu/matrix_R2: SW428.1, SW429.1, SW430.1, SW431.1, SW432.1, SW433.1, SW434.1, SW435.1, SW436.1, SW437.1, SW438.1, SW439.1, SW440.1, SW441.1; also elsewhere on the board
unnamed: D401.2 (A), SW401.2
unnamed: D402.2 (A), SW402.2
unnamed: D403.2 (A), SW403.2
unnamed: D404.2 (A), SW404.2
unnamed: D405.2 (A), SW405.2
unnamed: D406.2 (A), SW406.2
unnamed: D407.2 (A), SW407.2
unnamed: D408.2 (A), SW408.2
unnamed: D409.2 (A), SW409.2
unnamed: D410.2 (A), SW410.2
unnamed: D411.2 (A), SW411.2
unnamed: D412.2 (A), SW412.2
unnamed: D413.2 (A), SW413.2
unnamed: D414.2 (A), SW414.2
unnamed: D415.2 (A), SW415.2
unnamed: D416.2 (A), SW416.2
unnamed: D417.2 (A), SW417.2
unnamed: D418.2 (A), SW418.2
unnamed: D419.2 (A), SW419.2
unnamed: D420.2 (A), SW420.2
unnamed: D421.2 (A), SW421.2
unnamed: D422.2 (A), SW422.2
unnamed: D423.2 (A), SW423.2
unnamed: D424.2 (A), SW424.2
unnamed: D425.2 (A), SW425.2
unnamed: D426.2 (A), SW426.2
unnamed: D427.2 (A), SW427.2
unnamed: D428.2 (A), SW428.2
unnamed: D429.2 (A), SW429.2
unnamed: D430.2 (A), SW430.2
unnamed: D431.2 (A), SW431.2
unnamed: D432.2 (A), SW432.2
unnamed: D433.2 (A), SW433.2
unnamed: D434.2 (A), SW434.2
unnamed: D435.2 (A), SW435.2
unnamed: D436.2 (A), SW436.2
unnamed: D437.2 (A), SW437.2
unnamed: D438.2 (A), SW438.2
unnamed: D439.2 (A), SW439.2
unnamed: D440.2 (A), SW440.2
unnamed: D441.2 (A), SW441.2

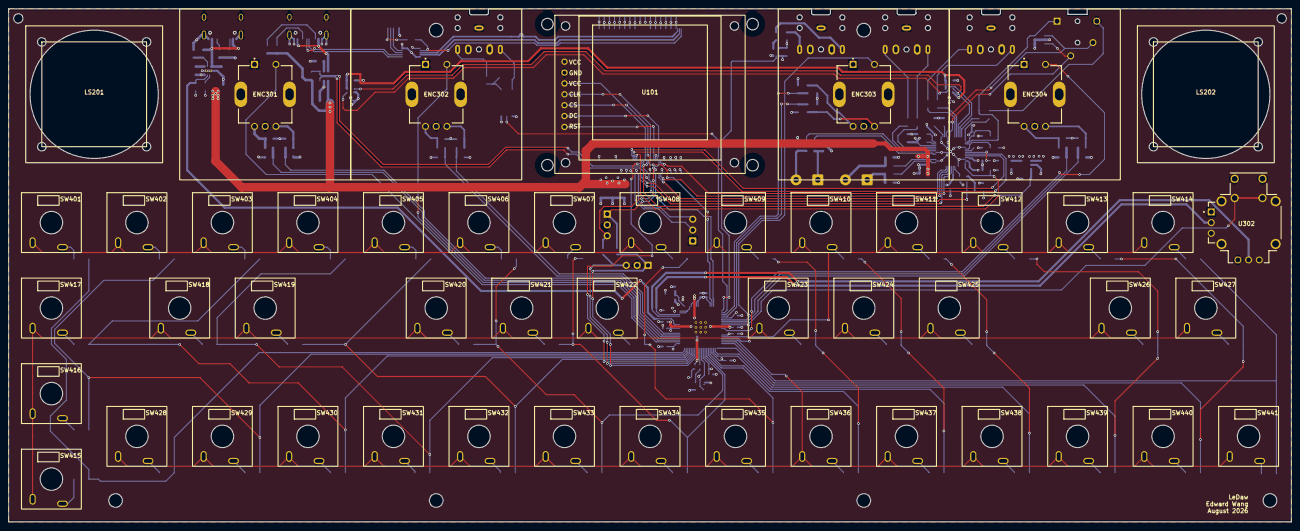
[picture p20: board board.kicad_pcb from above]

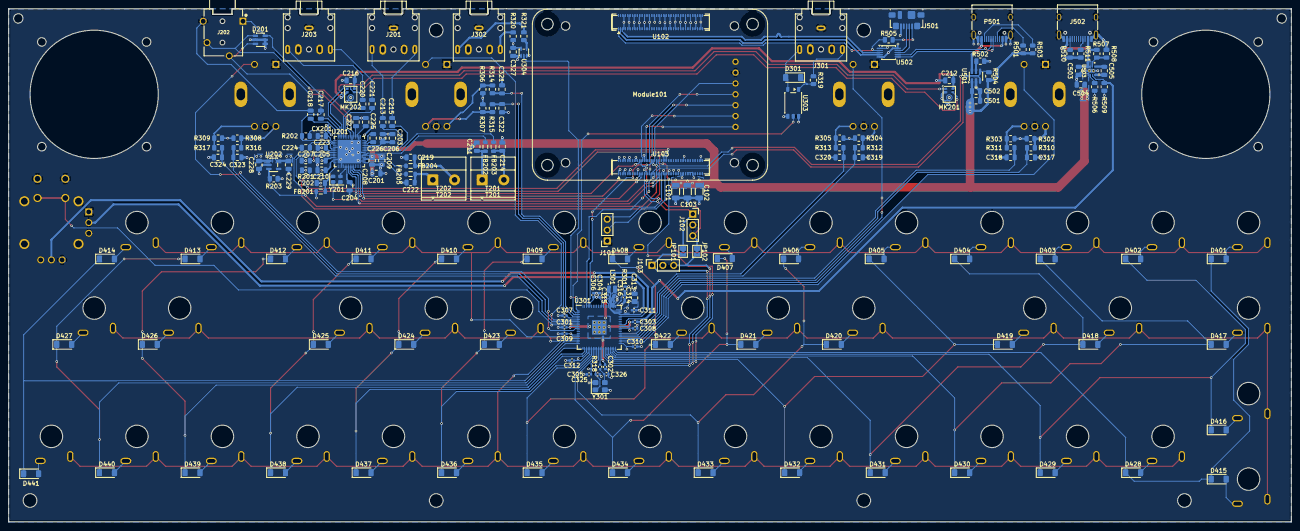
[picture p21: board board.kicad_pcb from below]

Board: 4 copper layers, 300.0 x 120.0 mm, 228 parts (179 on the bottom side), 175 nets.

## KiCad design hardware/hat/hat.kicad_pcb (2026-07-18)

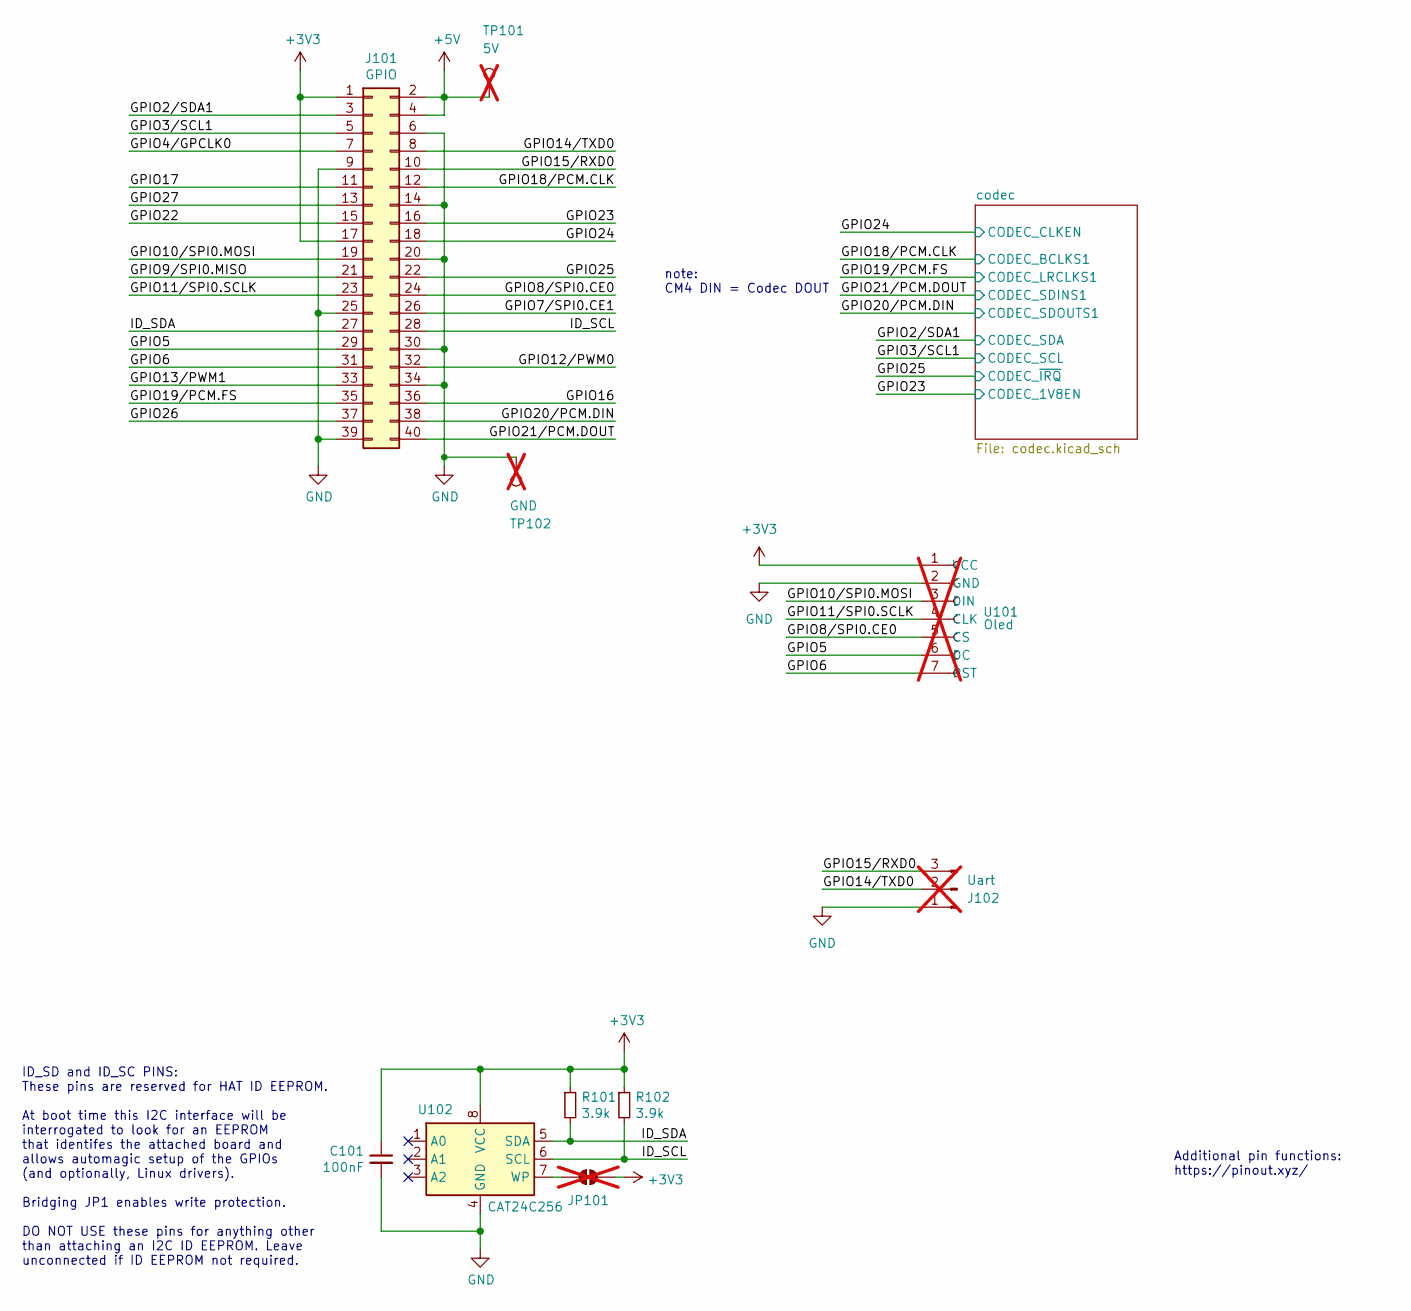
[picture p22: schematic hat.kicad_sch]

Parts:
C101: 100nF; C_0805_2012Metric; LCSC C49678
J101: GPIO; PinSocket_2x20_P2.54mm_Vertical; LCSC C2977589
J102: Uart; PinHeader_1x03_P2.54mm_Vertical; not fitted
JP101: ID_WP; SolderJumper-2_P1.3mm_Open_RoundedPad1.0x1.5mm; not fitted
R101, R102: 3.9k; R_0805_2012Metric; LCSC C17614
TP101: 5V; TestPoint_THTPad_1.5x1.5mm_Drill0.7mm; not fitted
TP102: GND; TestPoint_THTPad_1.5x1.5mm_Drill0.7mm; not fitted
U101: Oled; PinHeader_1x07_P2.54mm_Vertical; not fitted
U102: CAT24C256; SOIC-8_3.9x4.9mm_P1.27mm; LCSC C79987

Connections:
+3V3: C101.1, J101.1, J101.17, JP101.2 (B), R101.1, R102.1, U101.1 (VCC), U102.8 (VCC); also elsewhere on the board
+5V: J101.2, J101.4, TP101.1 (1_1); also elsewhere on the board
/GPIO2/SDA1: J101.3; also elsewhere on the board
/GPIO3/SCL1: J101.5; also elsewhere on the board
/GPIO4/GPCLK0: J101.7
/GPIO5: J101.29, U101.6 (DC)
/GPIO6: J101.31, U101.7 (RST)
/GPIO7/SPI0.CE1: J101.26
/GPIO8/SPI0.CE0: J101.24, U101.5 (CS)
/GPIO9/SPI0.MISO: J101.21
/GPIO10/SPI0.MOSI: J101.19, U101.3 (DIN)
/GPIO11/SPI0.SCLK: J101.23, U101.4 (CLK)
/GPIO12/PWM0: J101.32
/GPIO13/PWM1: J101.33
/GPIO14/TXD0: J101.8, J102.2
/GPIO15/RXD0: J101.10, J102.3
/GPIO16: J101.36
/GPIO17: J101.11
/GPIO18/PCM.CLK: J101.12; also elsewhere on the board
/GPIO19/PCM.FS: J101.35; also elsewhere on the board
/GPIO20/PCM.DIN: J101.38; also elsewhere on the board
/GPIO21/PCM.DOUT: J101.40; also elsewhere on the board
/GPIO22: J101.15
/GPIO23: J101.16; also elsewhere on the board
/GPIO24: J101.18; also elsewhere on the board
/GPIO25: J101.22; also elsewhere on the board
/GPIO26: J101.37
/GPIO27: J101.13
/ID_SCL: J101.28, R102.2, U102.6 (SCL)
/ID_SDA: J101.27, R101.2, U102.5 (SDA)
GND: C101.2, J101.6, J101.9, J101.14, J101.20, J101.25, J101.30, J101.34, J101.39, J102.1, TP102.1 (1_1), U101.2 (GND), U102.4 (GND); also elsewhere on the board
unnamed: JP101.1 (A), U102.7 (WP)

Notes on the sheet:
Additional pin functions: https://pinout.xyz/
ID_SD and ID_SC PINS: These pins are reserved for HAT ID EEPROM. At boot time this I2C interface will be interrogated to look for an EEPROM that identifes the attached board and allows automagic setup of the GPIOs (and optionally, Linux drivers). Bridging JP1 enables write protection. DO NOT USE th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
note: CM4 DIN = Codec DOUT

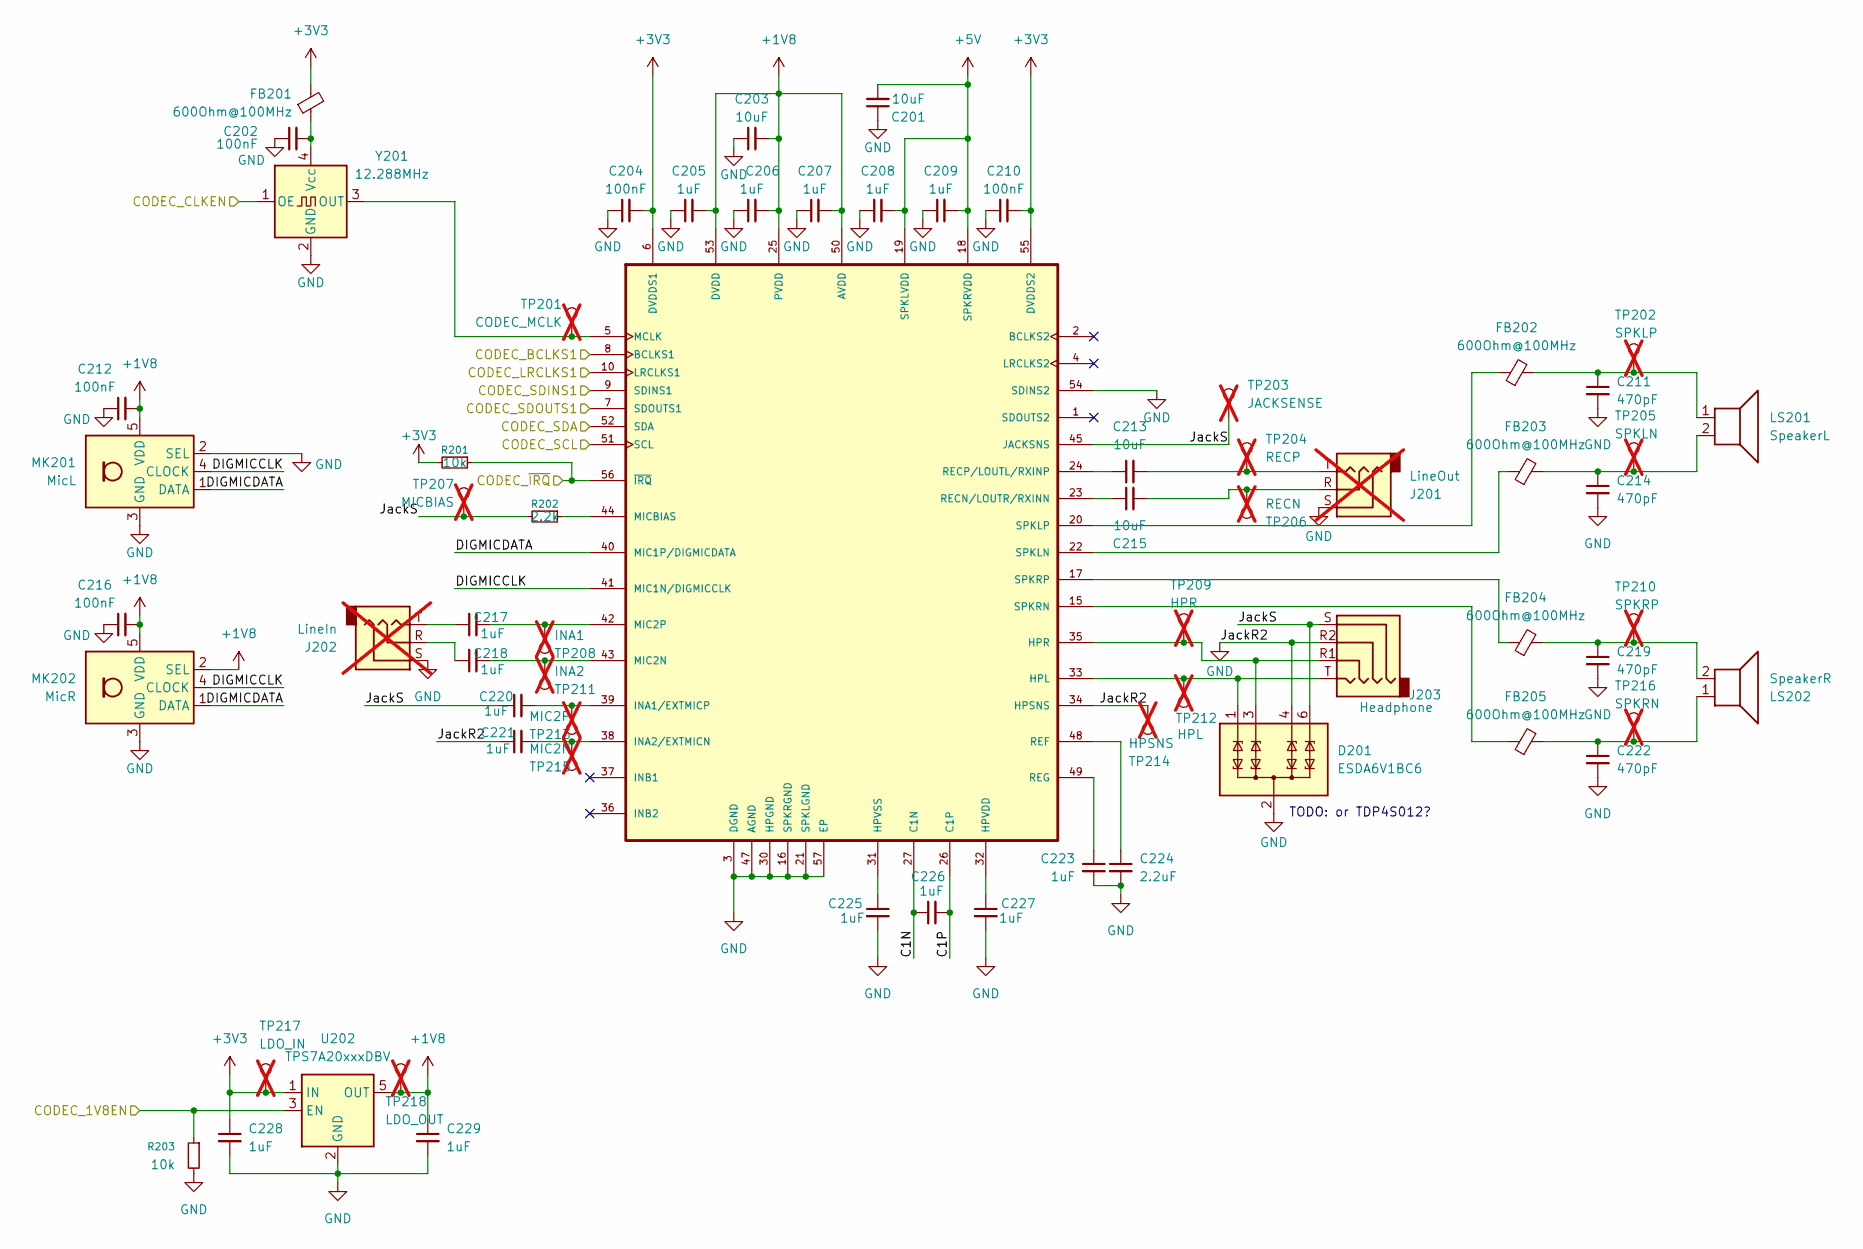
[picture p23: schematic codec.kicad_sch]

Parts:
C201, C203, C213, C215: 10uF; C_0805_2012Metric; LCSC C15850
C202, C204, C210, C212, C216: 100nF; C_0805_2012Metric; LCSC C49678
C205, C206, C207, C208, C209, C217, C218, C220, C221, C223, C225, C226, C227, C228, C229: 1uF; C_0805_2012Metric; LCSC C28323
C211, C214, C219, C222: 470pF; C_0805_2012Metric; LCSC C1743
C224: 2.2uF; C_0805_2012Metric; LCSC C377773
D201: ESDA6V1BC6; SOT-23-6; LCSC C495220
FB201, FB202, FB203, FB204, FB205: 600Ohm@100MHz; L_0805_2012Metric; LCSC C341663
J201: LineOut; Jack_3.5mm_CUI_SJ-3523-SMT_Horizontal; not fitted
J202: LineIn; Jack_3.5mm_CUI_SJ-3523-SMT_Horizontal; not fitted
J203: Headphone; CUI_SJ-43514-SMT-TR; LCSC C4992301
LS201: SpeakerL; TerminalBlock_Phoenix_MKDS-1,5-2-5.08_1x02_P5.08mm_Horizont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; LCSC C474881
LS202: SpeakerR; TerminalBlock_Phoenix_MKDS-1,5-2-5.08_1x02_P5.08mm_Horizont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; LCSC C474881
MK201: MicL; Knowles_LGA-5_3.5x2.65mm; LCSC C2879853
MK202: MicR; Knowles_LGA-5_3.5x2.65mm; LCSC C2879853
R201, R203: 10k; R_0805_2012Metric; LCSC C17414
R202: 2.2k; R_0805_2012Metric; LCSC C17520
TP201: CODEC_MCLK; TestPoint_Pad_D2.0mm; not fitted
TP202: SPKLP; TestPoint_Pad_D2.0mm; not fitted
TP203: JACKSENSE; TestPoint_Pad_D2.0mm; not fitted
TP204: RECP; TestPoint_Pad_D2.0mm; not fitted
TP205: SPKLN; TestPoint_Pad_D2.0mm; not fitted
TP206: RECN; TestPoint_Pad_D2.0mm; not fitted
TP207: MICBIAS; TestPoint_Pad_D2.0mm; not fitted
TP208: INA1; TestPoint_Pad_D2.0mm; not fitted
TP209: HPR; TestPoint_Pad_D2.0mm; not fitted
TP210: SPKRP; TestPoint_Pad_D2.0mm; not fitted
TP211: INA2; TestPoint_Pad_D2.0mm; not fitted
TP212: HPL; TestPoint_Pad_D2.0mm; not fitted
TP213: MIC2P; TestPoint_Pad_D2.0mm; not fitted
TP214: HPSNS; TestPoint_Pad_D2.0mm; not fitted
TP215: MIC2N; TestPoint_Pad_D2.0mm; not fitted
TP216: SPKRN; TestPoint_Pad_D2.0mm; not fitted
TP217: LDO_IN; TestPoint_Pad_D2.0mm; not fitted
TP218: LDO_OUT; TestPoint_Pad_D2.0mm; not fitted
U201: MAX98089ETN_T; LCSC C2651816
U202: TPS7A20xxxDBV; SOT-23-5; LCSC C2862740
Y201: 12.288MHz; Oscillator_SMD_SeikoEpson_SG210-4Pin_2.5x2.0mm; LCSC C20617595

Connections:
+1V8: C203.2, C205.2, C206.2, C207.2, C212.2, C216.2, C229.1, MK201.5 (VDD), MK202.2 (SEL), MK202.5 (VDD), TP218.1 (1_1), U201.25 (PVDD), U201.50 (AVDD), U201.53 (DVDD), U202.5 (OUT)
+3V3: C204.2, C210.2, C228.1, FB201.2, R201.2, TP217.1 (1_1), U201.6 (DVDDS1), U201.55 (DVDDS2), U202.1 (IN); also elsewhere on the board
+5V: C201.2, C208.2, C209.2, U201.18 (SPKRVDD), U201.19 (SPKLVDD); also elsewhere on the board
/GPIO2/SDA1: U201.52 (SDA); also elsewhere on the board
/GPIO3/SCL1: U201.51 (SCL); also elsewhere on the board
/GPIO18/PCM.CLK: U201.8 (BCLKS1); also elsewhere on the board
/GPIO19/PCM.FS: U201.10 (LRCLKS1); also elsewhere on the board
/GPIO20/PCM.DIN: U201.7 (SDOUTS1); also elsewhere on the board
/GPIO21/PCM.DOUT: U201.9 (SDINS1); also elsewhere on the board
/GPIO23: R203.1, U202.3 (EN); also elsewhere on the board
/GPIO24: Y201.1 (OE); also elsewhere on the board
/GPIO25: R201.1, U201.56 (~IRQ); also elsewhere on the board
/codec/C1N: C226.1, U201.27 (C1N)
/codec/C1P: C226.2, U201.26 (C1P)
/codec/DIGMICCLK: MK201.4 (CLOCK), MK202.4 (CLOCK), U201.41 (MIC1N/DIGMICCLK)
/codec/DIGMICDATA: MK201.1 (DATA), MK202.1 (DATA), U201.40 (MIC1P/DIGMICDATA)
/codec/JackS: C220.1, D201.6 (TVS4), J203.S, R202.2, TP203.1 (1_1), TP207.1 (1_1), U201.45 (JACKSNS)
GND: C201.1, C202.1, C203.1, C204.1, C205.1, C206.1, C207.1, C208.1, C209.1, C210.1, C211.2, C212.1, C214.2, C216.1, C219.2, C221.1, C222.2, C223.2, C224.2, C225.2, C227.2, C228.2, C229.2, D201.2 (COM), D201.4 (TVS3), D201.5 (COM), J201.S, J202.S, J203.R2, MK201.2 (SEL), MK201.3 (GND), MK202.3 (GND), R203.2, TP214.1 (1_1), U201.3 (DGND), U201.16 (SPKRGND), U201.21 (SPKLGND), U201.30 (HPGND), U201.34 (HPSNS), U201.47 (AGND), U201.54 (SDINS2), U201.57 (EP), U202.2 (GND), Y201.2 (GND); also elsewhere on the board
unnamed: C211.1, FB202.2, LS201.1, TP202.1 (1_1)
unnamed: C213.2, J201.T, TP204.1 (1_1)
unnamed: C214.1, FB203.2, LS201.2, TP205.1 (1_1)
unnamed: C215.2, J201.R, TP206.1 (1_1)
unnamed: C217.1, J202.T
unnamed: C218.1, J202.R
unnamed: C219.1, FB204.2, LS202.2, TP210.1 (1_1)
unnamed: C222.1, FB205.2, LS202.1, TP216.1 (1_1)
unnamed: D201.1 (TVS1), J203.T, TP212.1 (1_1), U201.33 (HPL)
unnamed: D201.3 (TVS2), J203.R1, TP209.1 (1_1), U201.35 (HPR)
unnamed: C227.1, U201.32 (HPVDD)
unnamed: C225.1, U201.31 (HPVSS)
unnamed: C220.2, TP213.1 (1_1), U201.39 (INA1/EXTMICP)
unnamed: C221.2, TP215.1 (1_1), U201.38 (INA2/EXTMICN)
unnamed: TP201.1 (1_1), U201.5 (MCLK), Y201.3 (OUT)
unnamed: C218.2, TP211.1 (1_1), U201.43 (MIC2N)
unnamed: C217.2, TP208.1 (1_1), U201.42 (MIC2P)
unnamed: R202.1, U201.44 (MICBIAS)
unnamed: C215.1, U201.23 (RECN/LOUTR/RXINN)
unnamed: C213.1, U201.24 (RECP/LOUTL/RXINP)
unnamed: C224.1, U201.48 (REF)
unnamed: C223.1, U201.49 (REG)
unnamed: FB203.1, U201.22 (SPKLN)
unnamed: FB202.1, U201.20 (SPKLP)
unnamed: FB205.1, U201.15 (SPKRN)
unnamed: FB204.1, U201.17 (SPKRP)
unnamed: C202.2, FB201.1, Y201.4 (Vcc)

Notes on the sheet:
TODO: or TDP4S012?



Board: 4 copper layers, 65.0 x 56.0 mm, 80 parts (18 on the bottom side), 55 nets.

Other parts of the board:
MH1, MH2, MH3, MH4: MountingHole_2.7mm_M2.5

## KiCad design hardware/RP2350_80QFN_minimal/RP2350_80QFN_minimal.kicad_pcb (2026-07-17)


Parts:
C301, C302, C319: 10u; C_0805_2012Metric
C303, C305, C306, C307, C308, C309, C310, C311, C312, C313, C314, C318: 100n; C_0402_1005Metric
C304, C315: 4.7u; C_0402_1005Metric
C316, C317: 4.7u; C_0402_1005Metric_small_pads
C320: DNF; C_0402_1005Metric
C321, C322: 15p; C_0402_1005Metric
H301, H302, H303, H304: MountingHole; MountingHole_2.7mm_M2.5
J301: USB_B_Micro; USB_Micro-B_Amphenol_10103594-0001LF_Horizontal
J302, J303: Conn_02x26_Odd_Even; PinHeader_2x26_P2.54mm_Vertical
J304: SM03B-SRSS-TB; JST_SH_SM03B-SRSS-TB_1x03-1MP_P1.00mm_Horizontal
L301: 3.3u; L_pol_2016
R301: 33; R_0402_1005Metric
R302, R303: 27; R_0402_1005Metric
R304, R305, R309, R310: DNF; R_0402_1005Metric
R306, R308, R311: 1k; R_0402_1005Metric
R307: 0; R_0402_1005Metric
SW301, SW302: SW_Push; SW_Push_1P1T_NO_Vertical_Wuerth_434133025816
U301: NCP1117-3.3_SOT223; SOT-223-3_TabPin2
U302: W25Q128JVS; SOIC-8_5.23x5.23mm_P1.27mm
U303: RP2350_80QFN; RP2350-QFN-80-1EP_10x10_P0.4mm_EP3.4x3.4mm_ThermalVias
U304: DNF; SOIC-8_5.23x5.23mm_P1.27mm
Y301: ABM8-272-T3; Crystal_SMD_3225-4Pin_3.2x2.5mm

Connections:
+1V1: C303.1, C304.1, C305.1, C317.1, L301.1, U303.10 (DVDD), U303.32 (DVDD), U303.51 (DVDD), U303.65 (VREG_FB)
+3V3: C302.1, C306.1, C307.1, C308.1, C309.1, C310.1, C311.1, C312.1, C313.1, C314.1, C316.1, C318.1, C319.1, C320.1, J302.2, R301.1, R304.1, R309.1, U301.2 (VO), U302.8 (VCC), U303.5 (IOVDD), U303.15 (IOVDD), U303.24 (IOVDD), U303.29 (IOVDD), U303.41 (IOVDD), U303.50 (IOVDD), U303.59 (ADC_AVDD), U303.60 (IOVDD), U303.64 (VREG_VIN), U303.68 (USB_OTP_VDD), U303.69 (QSPI_IOVDD), U303.76 (IOVDD), U304.8 (VCC)
/FLASH2_SS: R309.2, R310.2, U304.1 (~CS)
/FLASH_SS: R304.2, R305.2, R307.2, U302.1 (~CS)
/GPIO0: J302.4, R305.1, R310.1, U303.77 (GPIO0)
/GPIO1: J302.6, U303.78 (GPIO1)
/GPIO2: J302.8, U303.79 (GPIO2)
/GPIO3: J302.10, U303.80 (GPIO3)
/GPIO4: J302.12, U303.1 (GPIO4)
/GPIO5: J302.14, U303.2 (GPIO5)
/GPIO6: J302.16, U303.3 (GPIO6)
/GPIO7: J302.18, U303.4 (GPIO7)
/GPIO8: J302.20, U303.6 (GPIO8)
/GPIO9: J302.22, U303.7 (GPIO9)
/GPIO10: J302.24, U303.8 (GPIO10)
/GPIO11: J302.26, U303.9 (GPIO11)
/GPIO12: J302.28, U303.11 (GPIO12)
/GPIO13: J302.30, U303.12 (GPIO13)
/GPIO14: J302.32, U303.13 (GPIO14)
/GPIO15: J302.34, U303.14 (GPIO15)
/GPIO16: J302.36, U303.16 (GPIO16)
/GPIO17: J302.38, U303.17 (GPIO17)
/GPIO18: J302.40, U303.18 (GPIO18)
/GPIO19: J302.42, U303.19 (GPIO19)
/GPIO20: J302.44, U303.20 (GPIO20)
/GPIO21: J302.46, U303.21 (GPIO21)
/GPIO22: J302.48, U303.22 (GPIO22)
/GPIO23: J302.50, U303.23 (GPIO23)
/GPIO24: J302.52, U303.25 (GPIO24)
/GPIO25: J303.51, U303.26 (GPIO25)
/GPIO26: J303.49, U303.27 (GPIO26)
/GPIO27: J303.47, U303.28 (GPIO27)
/GPIO28: J303.39, U303.36 (GPIO28)
/GPIO29: J303.37, U303.37 (GPIO29)
/GPIO30: J303.35, U303.38 (GPIO30)
/GPIO31: J303.33, U303.39 (GPIO31)
/GPIO32: J303.31, U303.40 (GPIO32)
/GPIO33: J303.29, U303.42 (GPIO33)
/GPIO34: J303.27, U303.43 (GPIO34)
/GPIO35: J303.25, U303.44 (GPIO35)
/GPIO36: J303.23, U303.45 (GPIO36)
/GPIO37: J303.21, U303.46 (GPIO37)
/GPIO38: J303.19, U303.47 (GPIO38)
/GPIO39: J303.17, U303.48 (GPIO39)
/GPIO40_ADC0: J303.15, U303.49 (GPIO40_ADC0)
/GPIO41_ADC1: J303.13, U303.52 (GPIO41_ADC1)
/GPIO42_ADC2: J303.11, U303.53 (GPIO42_ADC2)
/GPIO43_ADC3: J303.9, U303.54 (GPIO43_ADC3)
/GPIO44_ADC4: J303.7, U303.55 (GPIO44_ADC4)
/GPIO45_ADC5: J303.5, U303.56 (GPIO45_ADC5)
/GPIO46_ADC6: J303.3, U303.57 (GPIO46_ADC6)
/GPIO47_ADC7: J303.1, U303.58 (GPIO47_ADC7)
/QSPI_SCLK: U302.6 (CLK), U303.71 (QSPI_SCLK), U304.6 (CLK)
/QSPI_SD0: U302.5 (DI(IO0)), U303.72 (QSPI_SD0), U304.5 (DI(IO0))
/QSPI_SD1: U302.2 (DO(IO1)), U303.74 (QSPI_SD1), U304.2 (DO(IO1))
/QSPI_SD2: U302.3 (IO2), U303.73 (QSPI_SD2), U304.3 (IO2)
/QSPI_SD3: U302.7 (IO3), U303.70 (QSPI_SD3), U304.7 (IO3)
/QSPI_SS: R306.1, R307.1, U303.75 (QSPI_SS)
/RUN: J303.41, SW302.2, U303.35 (RUN)
/SWCLK: J303.45, J304.1, U303.33 (SWCLK)
/SWD: J303.43, J304.3, U303.34 (SWD)
/USB_D+: J301.3 (D+), R302.1
/USB_D-: J301.2 (D-), R303.1
/VREG_AVDD: C315.1, R301.2, U303.61 (VREG_AVDD)
/VREG_LX: L301.2, U303.63 (VREG_LX)
/XIN: C321.1, U303.30 (XIN), Y301.1
/XOUT: R311.1, U303.31 (XOUT)
/~USB_BOOT: R306.2, SW301.2
GND: C301.2, C302.2, C303.2, C304.2, C305.2, C306.2, C307.2, C308.2, C309.2, C310.2, C311.2, C312.2, C313.2, C314.2, C315.2, C316.2, C317.2, C318.2, C319.2, C320.2, C321.2, C322.2, J301.5 (GND), J301.6 (Shield), J302.1, J302.3, J302.5, J302.7, J302.9, J302.11, J302.13, J302.15, J302.17, J302.19, J302.21, J302.23, J302.25, J302.27, J302.29, J302.31, J302.33, J302.35, J302.37, J302.39, J302.41, J302.43, J302.45, J302.47, J302.49, J302.51, J303.2, J303.4, J303.6, J303.8, J303.10, J303.12, J303.14, J303.16, J303.18, J303.20, J303.22, J303.24, J303.26, J303.28, J303.30, J303.32, J303.34, J303.36, J303.38, J303.40, J303.42, J303.44, J303.46, J303.48, J303.50, J303.52, J304.2, J304.MP (MountPin), R308.2, SW301.1, U301.1 (GND), U302.4 (GND), U303.62 (VREG_PGND), U303.81 (GND), U304.4 (GND), Y301.2, Y301.4
unnamed: C322.1, R311.2, Y301.3
unnamed: R308.1, SW302.1
unnamed: R303.2, U303.66 (USB_DM)
unnamed: R302.2, U303.67 (USB_DP)
VBUS: C301.1, J301.1 (VBUS), U301.3 (VI)

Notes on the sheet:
Optional Secondary flash or PSRAM (U4), using the second chip select (XIP_SS_N[1]) on GPIO0. N.B. Pull-up R13 will be required as GPIOs default to pull-downs at power-up.
IOs
12MHz Crystal
Primary Flash
JST Debug Connector
Make sure R7 and R8 are close to RP2350
Secondary Flash/PSRAM
Power



Board: 2 copper layers, 52.0 x 71.5 mm, 49 parts (4 on the bottom side), 74 nets.

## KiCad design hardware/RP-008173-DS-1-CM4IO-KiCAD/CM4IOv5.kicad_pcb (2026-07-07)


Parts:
H1, H2, H3, H4, H5, H6, H7, H8: MountingHole; MountingHole_2.7mm_M2.5; Part Description M2.5 mounting hole

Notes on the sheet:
Connectors ------- FAN Battery
Connector ------ PCIe x1
Connectors ------- DC Barrel Jack 4 pin power
Connectors ------- Dual USB microUSB
Connectors ------- Ethernet SDCARD 40way RPI Jumpers
Connectors ------- HDMI 0 HDMI 1 CSI 0 CSI 1 DSI 0 DSI 1


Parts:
C1: 100n; C_0402_1005Metric; Part Description 0.1uF 10% 16V Ceramic Capacitor X7R 040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
C5: 10u; C_0805_2012Metric; Part Description 10uF 10% 10V Ceramic Capacitor X7R 0805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
D1: LED Red; LED_0603_1608Metric; Part Description Red 620nm LED Indication - Discrete 2.2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
D2: LED Green; LED_0603_1608Metric; Part Description Green 572nm LED Indication - Discrete 2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
J1, J3: Conn_01x03; PinHeader_1x03_P2.54mm_Vertical; Part Description 3pin 0.1" connector
J2: Conn_02x07_Odd_Even; PinHeader_2x07_P2.54mm_Vertical; Part Description PinHeader_2x07_P2.54mm_Vertical
J7: Micro_SD_Card_Det; SDCARD_MOLEX_503398-1892; Part Description 9 (8 + 1) Position Card Connector micro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
J8: THD-20-R; PinHeader_2x20_P2.54mm_Vertical; Part Description PinHeader_2x20_P2.54mm_Vertical
J9: THD-02-R; PinHeader_2x02_P2.54mm_Vertical; Part Description PinHeader_2x02_P2.54mm_Vertical
Module1: ComputeModule4; Raspberry-Pi-4-Compute-Module; Part Description 100 Position Connector Receptacle, Cent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
R1, R10: 1k; R_0402_1005Metric; Part Description Resistor 1K M1005 1% 63mW
R2, R3: 470R; R_0402_1005Metric; Part Description Resistor 470R M1005 1% 63mW
R4: nf; R_0805_2012Metric_Pad1.15x1.40mm_HandSolder
R5: 0R; R_0805_2012Metric_Pad1.15x1.40mm_HandSolder; Part Description Resistor 0R M2012 5%
R17, R18: nf; R_0402_1005Metric; Part Description Resistor 1K M1005 1% 63mW
R29: 12K 1%; R_0402_1005Metric; Part Description Resistor 12K M1005 1% 63mW
TP3, TP5: TestPoint; TestPoint_Pad_2.0x2.0mm
U1, U2: TPD4EUSB30; USON-10_2.5x1.0mm_P0.5mm; Part Description Quad TVS diode for high speed signals (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
U3: MagJack-A70-112-331N126; TRJG0926HENL; Part Description Gigabit Ethernet Magjack
U5, U9: 74LVC1G07SE-7; SOT-353_SC-70-5; Part Description Buffer, Non-Inverting 1 Element 1 Bit p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
U18: RT9742GGJ5; SOT-23-5; Part Description Power Switch/Driver 1:1 N-Channel 1A TS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

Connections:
/+3.3v: D1.2 (A), D2.2 (A), J8.1, J8.17, Module1.84 (+3.3v_(Output)), Module1.86 (+3.3v_(Output)), R5.1, R17.1, R29.1, U3.15 (LEDG_A), U3.17 (LEDY_A), U5.5 (VCC), U18.5 (IN); also elsewhere on the board
/+5v: J8.2, J8.4, Module1.77 (+5v_(Input)), Module1.79 (+5v_(Input)), Module1.81 (+5v_(Input)), Module1.83 (+5v_(Input)), Module1.85 (+5v_(Input)), Module1.87 (+5v_(Input)), U9.5 (VCC); also elsewhere on the board
/CM4_GPIO ( Ethernet, GPIO, SDCARD)/+1.8v: Module1.88 (+1.8v_(Output)), Module1.90 (+1.8v_(Output)), R4.1
/CM4_GPIO ( Ethernet, GPIO, SDCARD)/AIN0: J2.5, Module1.96 (AnalogIP0)
/CM4_GPIO ( Ethernet, GPIO, SDCARD)/AIN1: J2.6, Module1.94 (AnalogIP1)
/CM4_GPIO ( Ethernet, GPIO, SDCARD)/BT_nDis: J3.3, Module1.91 (BT_nDisable)
/CM4_GPIO ( Ethernet, GPIO, SDCARD)/EEPROM_nWP: J2.4, Module1.20 (EEPROM_nWP)
/CM4_GPIO ( Ethernet, GPIO, SDCARD)/ETH_LEDG: Module1.17 (Ethernet_nLED2(3.3v)), R2.2
/CM4_GPIO ( Ethernet, GPIO, SDCARD)/ETH_LEDY: Module1.15 (Ethernet_nLED3(3.3v)), R3.2
/CM4_GPIO ( Ethernet, GPIO, SDCARD)/GLOBAL_EN: J1.1, J2.14, Module1.99 (Global_EN); also elsewhere on the board
/CM4_GPIO ( Ethernet, GPIO, SDCARD)/GPIO2: J8.3, Module1.58 (GPIO2)
/CM4_GPIO ( Ethernet, GPIO, SDCARD)/GPIO3: J8.5, Module1.56 (GPIO3)
/CM4_GPIO ( Ethernet, GPIO, SDCARD)/GPIO4: J8.7, Module1.54 (GPIO4)
/CM4_GPIO ( Ethernet, GPIO, SDCARD)/GPIO5: J8.29, Module1.34 (GPIO5)
/CM4_GPIO ( Ethernet, GPIO, SDCARD)/GPIO6: J8.31, Module1.30 (GPIO6)
/CM4_GPIO ( Ethernet, GPIO, SDCARD)/GPIO7: J8.26, Module1.37 (GPIO7)
/CM4_GPIO ( Ethernet, GPIO, SDCARD)/GPIO8: J8.24, Module1.39 (GPIO8)
/CM4_GPIO ( Ethernet, GPIO, SDCARD)/GPIO9: J8.21, Module1.40 (GPIO9)
/CM4_GPIO ( Ethernet, GPIO, SDCARD)/GPIO10: J8.19, Module1.44 (GPIO10)
/CM4_GPIO ( Ethernet, GPIO, SDCARD)/GPIO11: J8.23, Module1.38 (GPIO11)
/CM4_GPIO ( Ethernet, GPIO, SDCARD)/GPIO12: J8.32, Module1.31 (GPIO12)
/CM4_GPIO ( Ethernet, GPIO, SDCARD)/GPIO13: J8.33, Module1.28 (GPIO13)
/CM4_GPIO ( Ethernet, GPIO, SDCARD)/GPIO14: J8.8, Module1.55 (GPIO14)
/CM4_GPIO ( Ethernet, GPIO, SDCARD)/GPIO15: J8.10, Module1.51 (GPIO15)
/CM4_GPIO ( Ethernet, GPIO, SDCARD)/GPIO16: J8.36, Module1.29 (GPIO16)
/CM4_GPIO ( Ethernet, GPIO, SDCARD)/GPIO17: J8.11, Module1.50 (GPIO17)
/CM4_GPIO ( Ethernet, GPIO, SDCARD)/GPIO18: J8.12, Module1.49 (GPIO18)
/CM4_GPIO ( Ethernet, GPIO, SDCARD)/GPIO19: J8.35, Module1.26 (GPIO19)
/CM4_GPIO ( Ethernet, GPIO, SDCARD)/GPIO20: J8.38, Module1.27 (GPIO20)
/CM4_GPIO ( Ethernet, GPIO, SDCARD)/GPIO21: J8.40, Module1.25 (GPIO21)
/CM4_GPIO ( Ethernet, GPIO, SDCARD)/GPIO22: J8.15, Module1.46 (GPIO22)
/CM4_GPIO ( Ethernet, GPIO, SDCARD)/GPIO23: J8.16, Module1.47 (GPIO23)
/CM4_GPIO ( Ethernet, GPIO, SDCARD)/GPIO24: J8.18, Module1.45 (GPIO24)
/CM4_GPIO ( Ethernet, GPIO, SDCARD)/GPIO25: J8.22, Module1.41 (GPIO25)
/CM4_GPIO ( Ethernet, GPIO, SDCARD)/GPIO26: J8.37, Module1.24 (GPIO26)
/CM4_GPIO ( Ethernet, GPIO, SDCARD)/GPIO27: J8.13, Module1.48 (GPIO27)
/CM4_GPIO ( Ethernet, GPIO, SDCARD)/GPIO_VREF: Module1.78 (GPIO_VREF(1.8v/3.3v_Input)), R4.2, R5.2; also elsewhere on the board
/CM4_GPIO ( Ethernet, GPIO, SDCARD)/ID_SC: J8.28, Module1.35 (ID_SC); also elsewhere on the board
/CM4_GPIO ( Ethernet, GPIO, SDCARD)/ID_SD: J8.27, Module1.36 (ID_SD); also elsewhere on the board
/CM4_GPIO ( Ethernet, GPIO, SDCARD)/RUN_PG: J1.3, Module1.92 (RUN_PG), U9.2
/CM4_GPIO ( Ethernet, GPIO, SDCARD)/Reserved: Module1.76 (Reserved), R18.1
/CM4_GPIO ( Ethernet, GPIO, SDCARD)/SD_CLK: J7.5 (CLK), Module1.57 (SD_CLK)
/CM4_GPIO ( Ethernet, GPIO, SDCARD)/SD_CMD: J7.3 (CMD), Module1.62 (SD_CMD)
/CM4_GPIO ( Ethernet, GPIO, SDCARD)/SD_DAT0: J7.7 (DAT0), Module1.63 (SD_DAT0)
/CM4_GPIO ( Ethernet, GPIO, SDCARD)/SD_DAT1: J7.8 (DAT1), Module1.67 (SD_DAT1)
/CM4_GPIO ( Ethernet, GPIO, SDCARD)/SD_DAT2: J7.1 (DAT2), Module1.69 (SD_DAT2)
/CM4_GPIO ( Ethernet, GPIO, SDCARD)/SD_DAT3: J7.2 (DAT3/CD), Module1.61 (SD_DAT3)
/CM4_GPIO ( Ethernet, GPIO, SDCARD)/SD_PWR: C5.1, J7.4 (VDD), U18.1 (OUT)
/CM4_GPIO ( Ethernet, GPIO, SDCARD)/SD_PWR_ON: Module1.75 (SD_PWR_ON), R29.2, U18.4 (EN)
/CM4_GPIO ( Ethernet, GPIO, SDCARD)/SYNC_IN: J2.8, Module1.16 (Ethernet_SYNC_IN(1.8v))
/CM4_GPIO ( Ethernet, GPIO, SDCARD)/SYNC_OUT: J2.9, Module1.18 (Ethernet_SYNC_OUT(1.8v))
/CM4_GPIO ( Ethernet, GPIO, SDCARD)/TR0_TAP: J9.3, U3.11 (VC1)
/CM4_GPIO ( Ethernet, GPIO, SDCARD)/TR1_TAP: J9.1, U3.12 (VC2)
/CM4_GPIO ( Ethernet, GPIO, SDCARD)/TR2_TAP: J9.2, U3.13 (VC3)
/CM4_GPIO ( Ethernet, GPIO, SDCARD)/TR3_TAP: J9.4, U3.14 (VC4)
/CM4_GPIO ( Ethernet, GPIO, SDCARD)/TRD0_N: Module1.10 (Ethernet_Pair0_N), U2.4 (D2+), U2.7, U3.2 (TRD0-)
/CM4_GPIO ( Ethernet, GPIO, SDCARD)/TRD0_P: Module1.12 (Ethernet_Pair0_P), U2.5 (D2-), U2.6, U3.1 (TRD0+)
/CM4_GPIO ( Ethernet, GPIO, SDCARD)/TRD1_N: Module1.6 (Ethernet_Pair1_N), U2.2 (D1-), U2.9, U3.6 (TRD1-)
/CM4_GPIO ( Ethernet, GPIO, SDCARD)/TRD1_P: Module1.4 (Ethernet_Pair1_P), U2.1 (D1+), U2.10, U3.3 (TRD1+)
/CM4_GPIO ( Ethernet, GPIO, SDCARD)/TRD2_N: Module1.9 (Ethernet_Pair2_N), U1.4 (D2+), U1.7, U3.8 (TRD2-)
/CM4_GPIO ( Ethernet, GPIO, SDCARD)/TRD2_P: Module1.11 (Ethernet_Pair2_P), U1.5 (D2-), U1.6, U3.7 (TRD2+)
/CM4_GPIO ( Ethernet, GPIO, SDCARD)/TRD3_N: Module1.5 (Ethernet_Pair3_N), U1.2 (D1-), U1.9, U3.10 (TRD3-)
/CM4_GPIO ( Ethernet, GPIO, SDCARD)/TRD3_P: Module1.3 (Ethernet_Pair3_P), U1.1 (D1+), U1.10, U3.9 (TRD3+)
/CM4_GPIO ( Ethernet, GPIO, SDCARD)/TV_OUT: J2.11; also elsewhere on the board
/CM4_GPIO ( Ethernet, GPIO, SDCARD)/WL_nDis: J3.1, Module1.89 (WL_nDisable)
/CM4_GPIO ( Ethernet, GPIO, SDCARD)/nPWR_LED: Module1.95 (nPI_LED_PWR), U5.2
/CM4_GPIO ( Ethernet, GPIO, SDCARD)/nRPIBOOT: J2.2, Module1.93 (nRPIBOOT)
/CM4_HighSpeed/CAM_GPIO: Module1.97 (Camera_GPIO); also elsewhere on the board
/CM4_HighSpeed/SCL0: Module1.80 (SCL0); also elsewhere on the board
/CM4_HighSpeed/SDA0: Module1.82 (SDA0); also elsewhere on the board
/nEXTRST: Module1.100 (nEXTRST); also elsewhere on the board
GND: C1.2, C5.2, J1.2, J2.1, J2.3, J2.7, J2.10, J2.12, J3.2, J7.6 (VSS), J7.11 (SHIELD), J8.6, J8.9, J8.14, J8.20, J8.25, J8.30, J8.34, J8.39, Module1.1 (GND), Module1.2 (GND), Module1.7 (GND), Module1.8 (GND), Module1.13 (GND), Module1.14 (GND), Module1.22 (GND), Module1.23 (GND), Module1.32 (GND), Module1.33 (GND), Module1.42 (GND), Module1.43 (GND), Module1.52 (GND), Module1.53 (GND), Module1.59 (GND), Module1.60 (GND), Module1.65 (GND), Module1.66 (GND), Module1.71 (GND), Module1.74 (GND), Module1.98 (GND), U1.3 (GND), U1.8 (GND), U2.3 (GND), U2.8 (GND), U3.19 (SHIELD), U3.20 (SHIELD), U5.3 (GND), U9.3 (GND), U18.2 (GND); also elsewhere on the board
unnamed: C1.1, U3.4 (CT), U3.5 (CT)
unnamed: D1.1 (K), R10.1, TP5.1
unnamed: D2.1 (K), R1.1, TP3.1
unnamed: J2.13, U9.4
unnamed: J7.9 (DET_B), R18.2
unnamed: J7.10 (DET_A), R17.2
unnamed: Module1.21 (PI_nLED_Activity), R1.2
unnamed: R2.1, U3.16 (LEDG_K)
unnamed: R3.1, U3.18 (LEDY_K)
unnamed: R10.2, U5.4

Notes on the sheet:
PWR LED
Ethernet POE Protection
40Way GPIO Header
CM4Lite SDCARD I/F
GPIO Voltage select
Ethernet
Activity LED
EEPROM write protect = Jumper Pins 3-4
Not Fitted headers
A button between pins 13-14 can be used to wake up compute module from power down
If compute modules is awake RUN_PG will be high so the button doesn't do anything If the compute module is asleep then RUN_PG will be at 0v and so pull global enable low
Force RPIBOOT = Jumper Pins 1-2
POE Header

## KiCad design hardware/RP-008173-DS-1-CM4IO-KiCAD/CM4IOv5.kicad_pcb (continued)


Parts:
C12, C13: 100n; C_0402_1005Metric; Part Description 0.1uF 10% 16V Ceramic Capacitor X7R 040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
J4, J5, J15, J16: Conn_01x22_Female; Hirose_FH12-22S-0.5SH_1x22-1MP_P0.50mm_Horizontal; Part Description 22 Position FFC, FPC Connector Contacts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
J6: THD-02-R; PinHeader_2x02_P2.54mm_Vertical; Part Description PinHeader_2x02_P2.54mm_Vertical
J10, J22: 690-019-298-412; EDAC 690-019-298-412; Part Description HDMI Connector, Right Angle, 19 Contact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
Module1: ComputeModule4; Raspberry-Pi-4-Compute-Module; Part Description 100 Position Connector Receptacle, Cent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
R6, R7: 2.2K 1%; R_0402_1005Metric; Part Description Resistor 2.2K M1005 1% 63mW
U12: RT9742SNGV; SOT-23; Part Description Power Switch/Driver 1:1 N-Channel 500mA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

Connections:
/+3.3v: J4.22, J5.22, J15.22, J16.22; also elsewhere on the board
/+5v: C12.1, U12.1 (IN); also elsewhere on the board
/CM4_GPIO ( Ethernet, GPIO, SDCARD)/GPIO_VREF: R6.1, R7.1; also elsewhere on the board
/CM4_GPIO ( Ethernet, GPIO, SDCARD)/ID_SC: J6.1; also elsewhere on the board
/CM4_GPIO ( Ethernet, GPIO, SDCARD)/ID_SD: J6.3; also elsewhere on the board
/CM4_GPIO ( Ethernet, GPIO, SDCARD)/TV_OUT: Module1.111 (VDAC_COMP); also elsewhere on the board
/CM4_HighSpeed/CAM0_C_N: J4.8, Module1.140 (CAM0_C_N)
/CM4_HighSpeed/CAM0_C_P: J4.9, Module1.142 (CAM0_C_P)
/CM4_HighSpeed/CAM0_D0_N: J4.2, Module1.128 (CAM0_D0_N)
/CM4_HighSpeed/CAM0_D0_P: J4.3, Module1.130 (CAM0_D0_P)
/CM4_HighSpeed/CAM0_D1_N: J4.5, Module1.134 (CAM0_D1_N)
/CM4_HighSpeed/CAM0_D1_P: J4.6, Module1.136 (CAM0_D1_P)
/CM4_HighSpeed/CAM1_C_N: J5.8, Module1.127 (CAM1_C_N)
/CM4_HighSpeed/CAM1_C_P: J5.9, Module1.129 (CAM1_C_P)
/CM4_HighSpeed/CAM1_D0_N: J5.2, Module1.115 (CAM1_D0_N)
/CM4_HighSpeed/CAM1_D0_P: J5.3, Module1.117 (CAM1_D0_P)
/CM4_HighSpeed/CAM1_D1_N: J5.5, Module1.121 (CAM1_D1_N)
/CM4_HighSpeed/CAM1_D1_P: J5.6, Module1.123 (CAM1_D1_P)
/CM4_HighSpeed/CAM1_D2_N: J5.11, Module1.133 (CAM1_D2_N)
/CM4_HighSpeed/CAM1_D2_P: J5.12, Module1.135 (CAM1_D2_P)
/CM4_HighSpeed/CAM1_D3_N: J5.14, Module1.139 (CAM1_D3_N)
/CM4_HighSpeed/CAM1_D3_P: J5.15, Module1.141 (CAM1_D3_P)
/CM4_HighSpeed/CAM_GPIO: J4.17, J5.17; also elsewhere on the board
/CM4_HighSpeed/DSI0_C_N: J15.8, Module1.169 (DSI0_C_N)
/CM4_HighSpeed/DSI0_C_P: J15.9, Module1.171 (DSI0_C_P)
/CM4_HighSpeed/DSI0_D0_N: J15.2, Module1.157 (DSI0_D0_N)
/CM4_HighSpeed/DSI0_D0_P: J15.3, Module1.159 (DSI0_D0_P)
/CM4_HighSpeed/DSI0_D1_N: J15.5, Module1.163 (DSI0_D1_N)
/CM4_HighSpeed/DSI0_D1_P: J15.6, Module1.165 (DSI0_D1_P)
/CM4_HighSpeed/DSI1_C_N: J16.8, Module1.187 (DSI1_C_N)
/CM4_HighSpeed/DSI1_C_P: J16.9, Module1.189 (DSI1_C_P)
/CM4_HighSpeed/DSI1_D0_N: J16.2, Module1.175 (DSI1_D0_N)
/CM4_HighSpeed/DSI1_D0_P: J16.3, Module1.177 (DSI1_D0_P)
/CM4_HighSpeed/DSI1_D1_N: J16.5, Module1.181 (DSI1_D1_N)
/CM4_HighSpeed/DSI1_D1_P: J16.6, Module1.183 (DSI1_D1_P)
/CM4_HighSpeed/DSI1_D2_N: J16.11, Module1.193 (DSI1_D2_N)
/CM4_HighSpeed/DSI1_D2_P: J16.12, Module1.195 (DSI1_D2_P)
/CM4_HighSpeed/DSI1_D3_N: J16.14, Module1.194 (DSI1_D3_N)
/CM4_HighSpeed/DSI1_D3_P: J16.15, Module1.196 (DSI1_D3_P)
/CM4_HighSpeed/HDMI0_CEC: J22.13 (CEC), Module1.151 (HDMI0_CEC)
/CM4_HighSpeed/HDMI0_CK_N: J22.12 (CK-), Module1.190 (HDMI0_CLK_N)
/CM4_HighSpeed/HDMI0_CK_P: J22.10 (CK+), Module1.188 (HDMI0_CLK_P)
/CM4_HighSpeed/HDMI0_D0_N: J22.9 (D0-), Module1.184 (HDMI0_TX0_N)
/CM4_HighSpeed/HDMI0_D0_P: J22.7 (D0+), Module1.182 (HDMI0_TX0_P)
/CM4_HighSpeed/HDMI0_D1_N: J22.6 (D1-), Module1.178 (HDMI0_TX1_N)
/CM4_HighSpeed/HDMI0_D1_P: J22.4 (D1+), Module1.176 (HDMI0_TX1_P)
/CM4_HighSpeed/HDMI0_D2_N: J22.3 (D2-), Module1.172 (HDMI0_TX2_N)
/CM4_HighSpeed/HDMI0_D2_P: J22.1 (D2+), Module1.170 (HDMI0_TX2_P)
/CM4_HighSpeed/HDMI0_HOTPLUG: J22.19 (HPD/HEAC-), Module1.153 (HDMI0_HOTPLUG)
/CM4_HighSpeed/HDMI0_SCL: J22.15 (SCL), Module1.200 (HDMI0_SCL)
/CM4_HighSpeed/HDMI0_SDA: J22.16 (SDA), Module1.199 (HDMI0_SDA)
/CM4_HighSpeed/HDMI1_CEC: J10.13 (CEC), Module1.149 (HDMI1_CEC)
/CM4_HighSpeed/HDMI1_CK_N: J10.12 (CK-), Module1.166 (HDMI1_CLK_N)
/CM4_HighSpeed/HDMI1_CK_P: J10.10 (CK+), Module1.164 (HDMI1_CLK_P)
/CM4_HighSpeed/HDMI1_D0_N: J10.9 (D0-), Module1.160 (HDMI1_TX0_N)
/CM4_HighSpeed/HDMI1_D0_P: J10.7 (D0+), Module1.158 (HDMI1_TX0_P)
/CM4_HighSpeed/HDMI1_D1_N: J10.6 (D1-), Module1.154 (HDMI1_TX1_N)
/CM4_HighSpeed/HDMI1_D1_P: J10.4 (D1+), Module1.152 (HDMI1_TX1_P)
/CM4_HighSpeed/HDMI1_D2_N: J10.3 (D2-), Module1.148 (HDMI1_TX2_N)
/CM4_HighSpeed/HDMI1_D2_P: J10.1 (D2+), Module1.146 (HDMI1_TX2_P)
/CM4_HighSpeed/HDMI1_HOTPLUG: J10.19 (HPD/HEAC-), Module1.143 (HDMI1_HOTPLUG)
/CM4_HighSpeed/HDMI1_SCL: J10.15 (SCL), Module1.147 (HDMI1_SCL)
/CM4_HighSpeed/HDMI1_SDA: J10.16 (SDA), Module1.145 (HDMI1_SDA)
/CM4_HighSpeed/HDMI_5v: C13.1, J10.18 (+5V), J22.18 (+5V), U12.2 (OUT)
/CM4_HighSpeed/PCIE_CLK_N: Module1.112 (PCIe_CLK_N); also elsewhere on the board
/CM4_HighSpeed/PCIE_CLK_P: Module1.110 (PCIe_CLK_P); also elsewhere on the board
/CM4_HighSpeed/PCIE_CLK_nREQ: Module1.102 (PCIe_CLK_nREQ); also elsewhere on the board
/CM4_HighSpeed/PCIE_RX_N: Module1.118 (PCIe_RX_N); also elsewhere on the board
/CM4_HighSpeed/PCIE_RX_P: Module1.116 (PCIe_RX_P); also elsewhere on the board
/CM4_HighSpeed/PCIE_TX_N: Module1.124 (PCIe_TX_N); also elsewhere on the board
/CM4_HighSpeed/PCIE_TX_P: Module1.122 (PCIe_TX_P); also elsewhere on the board
/CM4_HighSpeed/PCIE_nRST: Module1.109 (PCIe_nRST); also elsewhere on the board
/CM4_HighSpeed/SCL0: J5.20, J16.20; also elsewhere on the board
/CM4_HighSpeed/SCL1: J4.20, J6.2, J15.20, R7.2
/CM4_HighSpeed/SDA0: J5.21, J16.21; also elsewhere on the board
/CM4_HighSpeed/SDA1: J4.21, J6.4, J15.21, R6.2
/CM4_HighSpeed/USB2_N: Module1.103 (USB2_N); also elsewhere on the board
/CM4_HighSpeed/USB2_P: Module1.105 (USB2_P); also elsewhere on the board
/CM4_HighSpeed/USBOTG_ID: Module1.101 (USB_OTG_ID); also elsewhere on the board
GND: C12.2, C13.2, J4.1, J4.4, J4.7, J4.10, J4.13, J4.16, J4.19, J5.1, J5.4, J5.7, J5.10, J5.13, J5.16, J5.19, J10.2 (D2S), J10.5 (D1S), J10.8 (D0S), J10.11 (CKS), J10.17 (GND), J10.SH1 (SH), J10.SH2 (SH), J10.SH3 (SH), J10.SH4 (SH), J15.1, J15.4, J15.7, J15.10, J15.13, J15.16, J15.19, J16.1, J16.4, J16.7, J16.10, J16.13, J16.16, J16.19, J22.2 (D2S), J22.5 (D1S), J22.8 (D0S), J22.11 (CKS), J22.17 (GND), J22.SH1 (SH), J22.SH2 (SH), J22.SH3 (SH), J22.SH4 (SH), Module1.107 (GND), Module1.108 (GND), Module1.113 (GND), Module1.114 (GND), Module1.119 (GND), Module1.120 (GND), Module1.125 (GND), Module1.126 (GND), Module1.131 (GND), Module1.132 (GND), Module1.137 (GND), Module1.138 (GND), Module1.144 (GND), Module1.150 (GND), Module1.155 (GND), Module1.156 (GND), Module1.161 (GND), Module1.162 (GND), Module1.167 (GND), Module1.168 (GND), Module1.173 (GND), Module1.174 (GND), Module1.179 (GND), Module1.180 (GND), Module1.185 (GND), Module1.186 (GND), Module1.191 (GND), Module1.192 (GND), Module1.197 (GND), Module1.198 (GND), U12.3 (GND); also elsewhere on the board

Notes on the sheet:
Jumpers to be fitted if Camera0 or Display0 are used.
Camera Connectors
Display Connectors


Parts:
C18: 100uF; CP_EIA-7343-31_Kemet-D; Part Description Capacitor, SP-Cap, 100u, 6.3V, 15mR ESR
C34, C35, C37, C38, C39, C41, C42: 10u 35v; C_0805_2012Metric; Part Description 10uF 10% or 20% 35V Ceramic Capacitor X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
C36: 100n 100v; C_0402_1005Metric; Part Description 0.1uF 10% 100V Ceramic Capacitor X5R 04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
C40, C57, C58: 100n; C_0402_1005Metric; Part Description 0.1uF 10% 16V Ceramic Capacitor X7R 040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
C47, C49, C51, C52: 10u; C_0805_2012Metric; Part Description 10uF 10% 10V Ceramic Capacitor X7R 0805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
C59: nf; C_0402_1005Metric
C60: 1.2nF; C_0402_1005Metric; Part Description 1200pF 10% 10V Ceramic Capacitor X5R 04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
C61: nf; C_0402_1005Metric; Part Description 220 pF, 50 V, 0402 [1005 Metric], ± 5%,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
D4: MMBZ5242BLT3G; D_SOT-23_ANK; Part Description Zener Diode 12V 225mW 5% Surface Mount 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
J19: Barrel_Jack; BarrelJack_Horizontal; Part Description DC Power Connectors PCB 2.1MM
J20: AMP171826-4; TE_171826-4; Part Description Wire-To-Board Connector, Right Angle, 2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
L5: SRN6045TA-3R3Y; L_Bourns_SRN6045TA; Part Description 3.3µH Semi-Shielded Wirewound Inductor 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
Q1: DMP3013SFV-7; Diodes_PowerDI3333-8; Part Description DMP3013SFV-7 - Power MOSFET, P Channel,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
R9: 10R; R_0402_1005Metric; Part Description Resistor 10R M1005 1% 63mW
R25: 20K 1%; R_0402_1005Metric; Part Description Resistor 20K M1005 1% 63mW
R26, R27: 12K 1%; R_0402_1005Metric; Part Description Resistor 12K M1005 1% 63mW
R28: 2.2K 1%; R_0402_1005Metric; Part Description Resistor 2.2K M1005 1% 63mW
TP2, TP4, TP6: TestPoint; TestPoint_Pad_2.0x2.0mm
U16: AP64501SP-13; SOIC-8-1EP_3.9x4.9mm_P1.27mm_EP2.95x4.9mm_Mask2.71x3.4mm_Th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; Part Description Buck Switching Regulator IC Positive Ad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

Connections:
/+5v: C18.1, C47.1, C49.1, C51.1, C52.1, C61.1, J20.4, L5.2, R27.1, TP4.1; also elsewhere on the board
/+12v: C34.1, C35.1, C37.1, C38.1, C39.1, C40.1, C41.1, C42.1, D4.1 (K), J20.1, Q1.1 (S), Q1.2 (S), Q1.3 (S), TP2.1, U16.2 (VIN), U16.3 (EN); also elsewhere on the board
GND: C18.2, C34.2, C35.2, C36.2, C37.2, C38.2, C39.2, C41.2, C42.2, C47.2, C49.2, C51.2, C52.2, C58.2, C59.2, C60.2, J19.2, J19.3, J20.2, J20.3, R26.2, R28.2, TP6.1, U16.7 (GND), U16.9 (EP); also elsewhere on the board
unnamed: C36.1, J19.1, Q1.5 (D)
unnamed: C40.2, D4.2 (A), Q1.4 (G), R26.1
unnamed: C57.1, R9.2
unnamed: C57.2, U16.1 (BST)
unnamed: C58.1, U16.4 (SS)
unnamed: C59.1, R25.1, U16.6 (COMP)
unnamed: C60.1, R25.2
unnamed: C61.2, R27.2, R28.1, U16.5 (FB)
unnamed: L5.1, R9.1, U16.8 (SW)

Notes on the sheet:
+12v Input
Can be used to power other devices if total loading on PSUs aren't exceeded
5v @ 3A PSU
+12v is only needed for PCIe and the FAN. If these aren't used then +12v isn't needed
Can be used to power the CM4IO board. NB +12v will also be available at the DC Jack
2.1mm Tip +ve
Ideal diode to prevent reverse polarity at the input
4 pin Power connector as found on Floppy drives
+5v @ 3A PSU ( 7.5v-28v Input )


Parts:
C2, C6, C10, C17, C19, C20, C21: 10u; C_0805_2012Metric; Part Description 10uF 10% 10V Ceramic Capacitor X7R 0805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
C3, C4, C7, C11, C14, C15: 100n; C_0402_1005Metric; Part Description 0.1uF 10% 16V Ceramic Capacitor X7R 040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
C8, C9: 27pF; C_0402_1005Metric; Part Description 27pF 5% 50V Ceramic Capacitor C0G, NP0 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
C16: 100uF; CP_EIA-7343-31_Kemet-D; Part Description Capacitor, SP-Cap, 100u, 6.3V, 15mR ESR
J11: USB_OTG; USB_Micro-B_EDAC_UCON00686; Part Description USB - micro B USB 2.0 Receptacle Connec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
J13: 690-008-221-904; MOLEX_USB_67298-4090; Part Description USB-A (USB TYPE-A), Stacked Receptacle 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
J14: Conn_02x05_Odd_Even; PinHeader_2x05_P2.54mm_Vertical; Part Description PinHeader_2x05_P2.54mm_Vertical
R8, R11: 2.2K 1%; R_0402_1005Metric; Part Description Resistor 2.2K M1005 1% 63mW
R12, R13, R14, R16: 36K 1%; R_0402_1005Metric; Part Description Resistor 36K M1005 1% 63mW
R15: 12K 1%; R_0402_1005Metric; Part Description Resistor 12K M1005 1% 63mW
R36: 15K 1%; R_0402_1005Metric; Part Description Resistor 15K M1005 1% 63mW
U4: TPD4EUSB30; USON-10_2.5x1.0mm_P0.5mm; Part Description Quad TVS diode for high speed signals (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
U6: USB2514B-I/M2; QFN-36-1EP_6x6mm_P0.5mm_EP3.7x3.7mm; Part Description USB Hub Controller USB Interface 36-SQF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
U7: AP22653W6; SOT-23-6; Part Description Power Switch/Driver 1:1 P-Channel 2.1A 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
U13: FSUSB42MUX; MSOP-10_3x3mm_P0.5mm; Part Description USB Switch IC 1 Channel 10-MSOP
Y1: 24MHz; Crystal_SMD_HC49-SD; Part Description 24MHz Crystal 18pf 30ppm 30ppm

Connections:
/+3.3v: C3.1, C4.1, C6.1, C7.1, C10.1, C11.1, C14.1, C15.1, U6.5 (VDDA33), U6.10 (VDDA33), U6.15 (VDD33), U6.23 (VDD33), U6.27 (VBUS_DET), U6.29 (VDDA33), U6.36 (VDDA33), U13.1 (VCC); also elsewhere on the board
/+5v: C2.1, U7.1 (IN); also elsewhere on the board
/CM4_HighSpeed/USB2_N: U13.4 (D_N); also elsewhere on the board
/CM4_HighSpeed/USB2_P: U13.3 (D_P); also elsewhere on the board
/CM4_HighSpeed/USBOTG_ID: R8.2, R11.1, U13.2 (SEL); also elsewhere on the board
/USB2-HUB/HD1_N: J13.2 (D-`), U6.1 (USBDM_DN1/PRT_DIS_M1)
/USB2-HUB/HD1_P: J13.3 (D+`), U6.2 (USBDP_DN1/PRT_DIS_P1)
/USB2-HUB/HD2_N: J13.6 (D-), U6.3 (USBDM_DN2/PRT_DIS_M2)
/USB2-HUB/HD2_P: J13.7 (D+), U6.4 (USBDP_DN2/PRT_DIS_P2)
/USB2-HUB/HD3_N: J14.3, U6.6 (USBDM_DN3/PRT_DIS_M3)
/USB2-HUB/HD3_P: J14.5, U6.7 (USBDP_DN3/PRT_DIS_P3)
/USB2-HUB/HD4_N: J14.4, U6.8 (USBDM_DN4/PRT_DIS_M4)
/USB2-HUB/HD4_P: J14.6, U6.9 (USBDP_DN4/PRT_DIS_P4)
/USB2-HUB/PWR1: U6.12 (PRTPWR1/BC_EN1), U7.3 (EN)
/USB2-HUB/USBD_N: J11.2 (D-), U4.4 (D2+), U4.7, U13.8 (HSD1_M)
/USB2-HUB/USBD_P: J11.3 (D+), U4.5 (D2-), U4.6, U13.9 (HSD1_P)
/USB2-HUB/USBH_N: U6.30 (USBDM_UP), U13.6 (HSD0_M)
/USB2-HUB/USBH_P: U6.31 (USBDP_UP), U13.7 (HSD0_P)
/USB2-HUB/VBUS: C16.1, C17.1, C19.1, C20.1, C21.1, J13.1 (VBUS`), J13.5 (VBUS), J14.1, J14.2, U7.6 (OUT)
/USB2-HUB/nOCS1: U6.13 (OCS_N1), U6.17 (OCS_N2), U6.19 (OCS_N3), U6.21 (OCS_N4), U7.4 (nFault)
/nEXTRST: U6.26 (RESET_N); also elsewhere on the board
GND: C2.2, C3.2, C4.2, C6.2, C7.2, C8.2, C9.2, C10.2, C11.2, C14.2, C15.2, C16.2, C17.2, C19.2, C20.2, C21.2, J11.5 (GND), J11.6 (Shield), J13.4 (GND`), J13.8 (GND), J13.MT1, J13.MT2, J13.MT3, J13.MT4, J14.7, J14.8, R11.2, R12.2, R13.2, R14.2, R15.1, R16.2, R36.2, U4.3 (GND), U4.8 (GND), U6.37 (VSS), U7.2 (GND), U13.5 (GND), U13.10 (nOE); also elsewhere on the board
unnamed: C8.1, U6.33 (XTALIN/CLKIN), Y1.1
unnamed: C9.1, U6.32 (XTALOUT), Y1.2
unnamed: J11.1 (VBUS), R8.1
unnamed: R12.1, U6.24 (SCL/SMBCLK/CFG_SEL0)
unnamed: R13.1, U6.22 (SDA/SMBDATA/NON_REM1)
unnamed: R14.1, U6.28 (SUSP_IND/LOCAL_PWR/NON_REM0)
unnamed: R15.2, U6.35 (RBIAS)
unnamed: R16.1, U6.25 (HS_IND/CFG_SEL1)
unnamed: R36.1, U7.5 (ILIM)
unnamed: U4.1 (D1+), U4.10
unnamed: U4.2 (D1-), U4.9

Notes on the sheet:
Expansion USB connector
Current Limit switch
USB 2.0 Hub
If a cable in plugged into the uUSB socket the CM4 becomes a usb device
Micro USB ESD protection
Stacked USB connectors


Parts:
BT1: Battery_Cell; BatteryHolder_Keystone_3034_1x20mm; Part Description Battery Retainer Coin, 20.0mm 1 Cell SM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
C22, C23, C24, C46: 100n; C_0402_1005Metric; Part Description 0.1uF 10% 16V Ceramic Capacitor X7R 040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
D3: BAT54C-7-F; SOT-23; Part Description Diode Array 1 Pair Common Cathode Schot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
J17: Molex 470531000; FanPinHeader_1x04_P2.54mm_Vertical; Part Description Connector Header Through Hole 4 positio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
R19, R20: 510K 1%; R_0402_1005Metric; Part Description Resistor 510K M1005 1% 63mW
R21: 36K 1%; R_0402_1005Metric; Part Description Resistor 36K M1005 1% 63mW
U8: PCF85063AT/AAZ; SOIC-8_3.9x4.9mm_P1.27mm; Part Description Real Time Clock (RTC) IC Clock/Calendar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
U11: EMC2301-1-ACZL-TR; MSOP-8_3x3mm_P0.65mm; Part Description Motor Driver PWM 8-MSOP
U14: 74LVC1G07SE-7; SOT-353_SC-70-5; Part Description Buffer, Non-Inverting 1 Element 1 Bit p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
Y2: X32K768S301; Crystal_SMD_3215-2Pin_3.2x1.5mm; Part Description Crystal 32.768KHz 7pF 20pmm

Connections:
/+3.3v: C23.1, D3.2, R21.2, U11.3 (VDD); also elsewhere on the board
/+5v: C22.1, R19.2, R20.2, U14.5 (VCC); also elsewhere on the board
/+12v: J17.2; also elsewhere on the board
/CM4_GPIO ( Ethernet, GPIO, SDCARD)/GLOBAL_EN: U14.4; also elsewhere on the board
/CM4_HighSpeed/SCL0: U8.6 (SCL), U11.2 (SCL); also elsewhere on the board
/CM4_HighSpeed/SDA0: U8.5 (SDA), U11.1 (SDA); also elsewhere on the board
/RTC , Wakeup, FAN/nRTC_INT: C24.2, R19.1, U8.3 (~INT)
GND: BT1.2 (-), C22.2, C23.2, C46.2, J17.1, U8.4 (VSS), U11.4 (GND), U14.3 (GND); also elsewhere on the board
unnamed: BT1.1 (+), D3.1
unnamed: C24.1, R20.1, U14.2
unnamed: C46.1, D3.3, U8.8 (VDD)
unnamed: J17.3, R21.1, U11.6 (TACH)
unnamed: J17.4, U11.5 (PWM)
unnamed: U8.1 (OSCI), Y2.2
unnamed: U8.2 (OSCO), Y2.1

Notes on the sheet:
RTC alarms can be used to wake up the Compute module NB an Alarm triggering while already awake will cause a reset This can be used as a watchdog reset
RTC and RTC wakeup
Also SMBUS alert IIC address : 0001_100x
IIC address : 0101_111x
IIC address : 1010_001x
GLOBAL_EN needs to be pulse low for >1mS
FAN controler
FAN connector
The above circuit generates a pulse for GLOBAL_EN when nRTC_INT goes low

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

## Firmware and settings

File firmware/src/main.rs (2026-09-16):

#![no_std]
#![no_main]

use core::fmt::Write as _;
use defmt::info;
use defmt_rtt as _;
use embedded_hal::digital::{InputPin, OutputPin};
use hal::uart::{DataBits, StopBits, UartConfig, UartPeripheral};
use panic_probe as _;
use rp235x_hal::clocks::init_clocks_and_plls;
use rp235x_hal::fugit::RateExtU32;
use rp235x_hal::{self as hal, entry};
use rp235x_hal::{Clock, pac};

// Provide an alias for our BSP so we can switch targets quickly.
// Uncomment the BSP you included in Cargo.toml, the rest of the code does not need to change.
// use some_bsp;

/// Tell the Boot ROM about our application
#[unsafe(link_section = ".start_block")]
#[used]
pub static IMAGE_DEF: hal::block::ImageDef = hal::block::ImageDef::secure_exe();

#[entry]
fn main() -> ! {
    info!("Program start");
    let mut pac = pac::Peripherals::take().unwrap();
    let core = cortex_m::Peripherals::take().unwrap();
    let mut watchdog = hal::Watchdog::new(pac.WATCHDOG);
    let sio = hal::Sio::new(pac.SIO);

    // External high-speed crystal on the pico board is 12Mhz
    let external_xtal_freq_hz = 12_000_000u32;
    let clocks = init_clocks_and_plls(
        external_xtal_freq_hz,
        pac.XOSC,
        pac.CLOCKS,
        pac.PLL_SYS,
        pac.PLL_USB,
        &mut pac.RESETS,
        &mut watchdog,
    )
    .ok()
    .unwrap();

    let mut delay = cortex_m::delay::Delay::new(core.SYST, clocks.system_clock.freq().to_Hz());

    let pins = hal::gpio::Pins::new(
        pac.IO_BANK0,
        pac.PADS_BANK0,
        sio.gpio_bank0,
        &mut pac.RESETS,
    );

    let uart_pins = (pins.gpio0.into_function(), pins.gpio1.into_function());
    let mut uart = UartPeripheral::new(pac.UART0, uart_pins, &mut pac.RESETS)
        .enable(
            UartConfig::new(115_200u32.Hz(), DataBits::Eight, None, StopBits::One),
            clocks.peripheral_clock.freq(),
        )
        .unwrap();

    // Rows are active high and idle rows are low so only the selected row can raise a column.
    let mut rows = [
        pins.gpio16.into_push_pull_output().into_dyn_pin(),
        pins.gpio17.into_push_pull_output().into_dyn_pin(),
        pins.gpio18.into_push_pull_output().into_dyn_pin(),
    ];
    for row in &mut rows {
        row.set_low().unwrap();
    }

    let mut columns = [
        pins.gpio32.into_pull_down_input().into_dyn_pin(),
        pins.gpio31.into_pull_down_input().into_dyn_pin(),
        pins.gpio30.into_pull_down_input().into_dyn_pin(),
        pins.gpio29.into_pull_down_input().into_dyn_pin(),
        pins.gpio28.into_pull_down_input().into_dyn_pin(),
        pins.gpio27.into_pull_down_input().into_dyn_pin(),
        pins.gpio26.into_pull_down_input().into_dyn_pin(),
        pins.gpio25.into_pull_down_input().into_dyn_pin(),
        pins.gpio24.into_pull_down_input().into_dyn_pin(),
        pins.gpio23.into_pull_down_input().into_dyn_pin(),
        pins.gpio22.into_pull_down_input().into_dyn_pin(),
        pins.gpio21.into_pull_down_input().into_dyn_pin(),
        pins.gpio20.into_pull_down_input().into_dyn_pin(),
        pins.gpio19.into_pull_down_input().into_dyn_pin(),
    ];
    let mut previous = [u16::MAX; 3];

    loop {
        let mut scan = [0u16; 3];

        for (row_index, row) in rows.iter_mut().enumerate() {
            row.set_high().unwrap();
            delay.delay_us(5);

            for (column_index, column) in columns.iter_mut().enumerate() {
                if column.is_high().unwrap() {
                    scan[row_index] |= 1 << column_index;
                }
            }

            row.set_low().unwrap();
        }

        if scan != previous {
            // Each bit is a pressed key; bit 0 is GPIO32 and bit 13 is GPIO19.
            info!(
                "matrix: {=u16:04x} {=u16:04x} {=u16:04x}",
                scan[0], scan[1], scan[2]
            );
            // send over uart (mostly as a test)
            write!(
                uart,
                "matrix: {:04x} {:04x} {:04x}\r\n",
                scan[0], scan[1], scan[2]
            )
            .unwrap();
            previous = scan;
        }

        delay.delay_ms(1);
    }
}

/// Program metadata for `picotool info`
#[unsafe(link_section = ".bi_entries")]
#[used]
pub static PICOTOOL_ENTRIES: [rp235x_hal::binary_info::EntryAddr; 5] = [
    rp235x_hal::binary_info::rp_cargo_bin_name!(),
    rp235x_hal::binary_info::rp_cargo_version!(),
    rp235x_hal::binary_info::rp_program_description!(c"RP2350 Template"),
    rp235x_hal::binary_info::rp_cargo_homepage_url!(),
    rp235x_hal::binary_info::rp_program_build_attribute!(),
];

// End of file

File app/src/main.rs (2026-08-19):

//! Desktop entry point. Ports `main.zig`'s setup (demo lead + bass tracks), the cpal audio
//! stream, and the raylib loop that renders into a 128x128 texture and blits it scaled to a
//! square in the window. Hardware/OLED path removed.
//!
//! Build/run the full app: `cargo run`

fn main() {
    use std::sync::{Arc, Mutex};

    use raylib::prelude::*;

    use ledaw::audio::AudioBuffer;
    use ledaw::audio_in;
    use ledaw::audio_out;
    use ledaw::engine::{AudioClip, Engine, Track, TrackSource};
    use ledaw::instrument::Instrument;
    use ledaw::instrument::juno::Juno;
    use ledaw::instrument::sampler::Sampler;
    use ledaw::interface::{self, HEIGHT, WIDTH};
    use ledaw::midi::{Note, beats_to_frames};
    use ledaw::ui::{App, Icons};

    // Engine must run at the device sample rate.
    let sr = audio_out::default_output_sample_rate().unwrap_or(48_000.0);
    let tempo = 120.0f32;

    let n = |b0: f32, b1: f32, note: u8| Note {
        start: beats_to_frames(b0, tempo, sr),
        end: beats_to_frames(b1, tempo, sr),
        note,
    };

    // Demo melody + bass (from main.zig).
    let lead = [
        n(0.0, 0.9, 60),
        n(1.0, 1.9, 60),
        n(2.0, 2.9, 67),
        n(3.0, 3.9, 67),
        n(4.0, 4.9, 69),
        n(5.0, 5.9, 69),
        n(6.0, 7.9, 67),
        n(8.0, 8.9, 65),
        n(9.0, 9.9, 65),
        n(10.0, 10.9, 64),
        n(11.0, 11.9, 64),
        n(12.0, 12.9, 62),
        n(13.0, 13.9, 62),
        n(14.0, 15.9, 60),
    ];
    let bass = [
        n(0.0, 2.0, 48),
        n(2.0, 4.0, 48),
        n(4.0, 6.0, 43),
        n(6.0, 8.0, 43),
        n(8.0, 10.0, 41),
        n(10.0, 12.0, 40),
        n(12.0, 14.0, 38),
        n(14.0, 16.0, 36),
    ];

    let mut engine = Engine::new(sr, tempo);
    engine.add_track(Track::new(TrackSource::Instrument {
        instrument: Instrument::Sampler(Sampler::default()),
        notes: lead.to_vec(),
    }));
    engine.add_track(Track::new(TrackSource::Instrument {
        instrument: Instrument::Juno(Juno::default()),
        notes: bass.to_vec(),
    }));

    let audio = AudioBuffer::decode_wav(include_bytes!("../assets/samples/pierre.wav"));
    let audio2 = AudioBuffer::decode_wav(include_bytes!("../assets/samples/perfect.wav"));
    engine.add_track(Track::new(TrackSource::Audio {
        clips: vec![
            AudioClip::new(0, audio),
            AudioClip::new(beats_to_frames(7.0, tempo, sr), audio2),
        ],
    }));
    let engine = Arc::new(Mutex::new(engine));

    // Audio stream (held until the end of main).
    let _audio = audio_out::start(engine.clone()).expect("failed to start audio");
    let _audio_in = match audio_in::start(engine.clone()) {
        Ok(audio_in) => Some(audio_in),
        Err(error) => {
            eprintln!("audio input unavailable: {error}");
            None
        }
    };

    // Window + 128x128 render target.
    let (mut rl, thread) = raylib::init().size(512, 512).title("LeDaw").build();
    rl.set_target_fps(60);
    rl.set_exit_key(None); // ESC shouldn't close

    let mut target = rl
        .load_render_texture(&thread, WIDTH as u32, HEIGHT as u32)
        .expect("render texture");

    let icons = Icons::load(&mut rl, &thread);
    let mut app = App::new(engine.clone(), icons);

    while !rl.window_should_close() {
        for ev in interface::poll_events(&rl) {
            app.handle_event(ev);
        }

        let screen_w = rl.get_screen_width();
        let screen_h = rl.get_screen_height();
        let side = screen_w.min(screen_h);
        let pos_x = (screen_w - side) as f32 / 2.0;
        let pos_y = (screen_h - side) as f32 / 2.0;

        let mut d = rl.begin_drawing(&thread);
        d.clear_background(Color::BLACK);

        // draw the app into the 128x128 texture
        {
            let mut td = d.begin_texture_mode(&thread, &mut target);
            td.clear_background(Color::BLACK);
            app.render(&mut td);
        }

        // blit the texture, scaled to a centered square (Y flipped, like the Zig version)
        let src = Rectangle::new(
            0.0,
            0.0,
            target.texture().width as f32,
            -(target.texture().height as f32),
        );
        let dest = Rectangle::new(pos_x, pos_y, side as f32, side as f32);
        d.draw_texture_pro(
            target.texture(),
            src,
            dest,
            Vector2::zero(),
            0.0,
            Color::WHITE,
        );
    }
}

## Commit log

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2026-03-08 hierarhcal event handle (#9)
    * wip projc
    * make that jawn compile
    * remove renudnadnt
    * add back timeline func, fix return case
    * smallfix
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2026-03-14 Fix trackindex (#28)
    * put track index in track
    * use backwards pointer insted of usize
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2026-03-22 actionlist, fix active_track (#60)
    * make handleEvent return ActionList
    * fixedlist
    * only edit active_track from audio thread
    * rename fixedlist -> boundedlist
2026-03-22 fix bugs found by fuzz test (#62)
    * bigger scratch
    * double capacity check
    * clamp in set_active_track
2026-05-10 hw: lemme get it started
    [MAX98089ETN_T.step, codec.kicad_sch, ledaw.kicad_pcb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]
2026-05-13 hw: headphone and wip mic
    [codec.kicad_sch]
2026-05-19 hw: big simplification
    [codec.kicad_sch]
2026-05-20 hw: speakers, line in/out. only missing digital mic now
    [codec.kicad_sch]
2026-05-20 hw: done codec?
    [codec.kicad_sch, ledaw.kicad_sch]
2026-05-20 hw: really close!!
    [hat.kicad_sch]
2026-05-21 hw: assign
    [codec.kicad_sch, hat.kicad_pcb, hat.kicad_sch]
2026-05-21 hw: sync
    [hat.kicad_pcb]
2026-05-21 hw: delete ledaw
    [MAX98089ETN_T.step, codec.kicad_sch, ledaw.kicad_pcb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]
2026-05-23 hw: placement
    [SJ-3523-SMT-TR.step, SJ-43514-SMT-TR.step, codec.kicad_sch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]
2026-05-24 place all components
    [hat.kicad_pcb]
2026-05-26 bypass cap
    [hat.kicad_pcb]
2026-06-03 all signal except ID chip
    [codec.kicad_sch, hat.kicad_pcb, hat.kicad_sch]
2026-06-03 all signals
    [hat.kicad_pcb, hat.kicad_sch]
2026-06-03 lil groundfil
    [hat.kicad_pcb]
2026-06-03 some troll power planes
    [hat.kicad_pcb]
2026-06-04 vias for planes
    [hat.kicad_pcb, hat.kicad_sch]
2026-06-05 before drc
    [hat.kicad_pcb, hat.kicad_sch]
2026-06-09 restore backup from June 6 1:34 AM
    [codec.kicad_sch, hat.kicad_pcb, hat.kicad_sch]
2026-06-18 lock ports
    [hat.kicad_pcb]
2026-06-26 BOARD: LET ME GET IT STARTED BB WITH THE ROBIN LOOKING ALL EDWARD WANG
    [board.kicad_pcb, board.kicad_sch, buttons.kicad_sch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]
2026-06-26 ports and shieeet
    [board.kicad_sch, mcu.kicad_sch]
2026-06-28 some 3d models
    [1_5inch-rgb-oled-module_asm-1110.stp, Gateron KS-33.step, pec11r-4015f-s0024.stp]
2026-07-04 upload rp2350 example
    [RP2350_80QFN_minimal.kicad_pcb, RP2350_80QFN_minimal.kicad_sch, RP2350_80QFN_minimal.sch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]
2026-07-04 add hella parts
    [audio.kicad_sch, board.kicad_pcb, board.kicad_sch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]
2026-07-05 hella footprints and trying out layouts
    [SJ-43514.step, audio.kicad_sch, board.kicad_pcb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]
2026-07-05 usb c footprint
    [board.kicad_pcb, board.kicad_sch]
2026-07-05 more placement
    [board.kicad_pcb, buttons.kicad_sch, mcu.kicad_sch]
2026-07-06 rp2350 pdf
    [board.kicad_pcb, board.kicad_sch]
2026-07-07 upload cm4 io board example
    [CM4IOv5-B_Cu.gbr, CM4IOv5-B_Mask.gbr, CM4IOv5-Edge_Cuts.gbr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]
2026-07-07 wip usb
    [board.kicad_pcb, board.kicad_sch, mcu.kicad_sch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]
2026-07-07 finish usb?
    [board.kicad_pcb, board.kicad_sch, usb.kicad_sch]
2026-07-07 upload cm4io pretty
    [Same_Sky_CLS0361-L152.x_t]
2026-07-07 finish assignment
    [board.kicad_pcb, board.kicad_sch, mcu.kicad_sch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]
2026-07-07 make key courtyard smaller
    [board.kicad_pcb]
2026-07-08 connecting main
    [board.kicad_pcb, board.kicad_sch, mcu.kicad_sch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]
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2026-07-08 wire evertying up
    [board.kicad_sch, usb.kicad_sch]
2026-07-08 cleanup paper
    [board.kicad_sch, mcu.kicad_sch]
2026-07-09 start audio codec
    [board.kicad_pcb]
2026-07-13 fix hpmic / linein mixup
    [audio.kicad_sch, board.kicad_pcb]
2026-07-13 wip doing the copy from hat
    [board.kicad_pcb]
2026-07-13 make hat 100 x sheetnum
    [codec.kicad_sch, hat.kicad_pcb, hat.kicad_sch]
2026-07-13 move ldo into audio sheet
    [codec.kicad_sch, hat.kicad_pcb, hat.kicad_sch]
2026-07-13 use H label for 1v8en
    [codec.kicad_sch, hat.kicad_pcb, hat.kicad_sch]
2026-07-13 reannoation with good linkage?
    [audio.kicad_sch, board.kicad_pcb, board.kicad_sch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]
2026-07-13 successfully got hat in?
    [board.kicad_pcb]
2026-07-13 some tidy still not sure if its linked right
    [board.kicad_pcb, board.kicad_sch]
2026-07-17 wip made a mistake adding micbias cap from hat
    [audio.kicad_sch, board.kicad_pcb]
2026-07-17 i think this is finally right
    [audio.kicad_sch, board.kicad_pcb, board.kicad_sch]
2026-07-17 progress on audio
    [board.kicad_pcb, board.kicad_sch]
2026-07-17 annotate 2350 example
    [RP2350_80QFN_minimal.kicad_pcb, RP2350_80QFN_minimal.kicad_sch]
2026-07-17 caps for 2350
    [board.kicad_pcb]
2026-07-18 big routing board
    [board.kicad_pcb, board.kicad_sch, mcu.kicad_sch]
2026-07-18 something small cat
    [hat.kicad_pcb]
2026-07-22 some big tim routing
    [audio.kicad_sch, board.kicad_pcb, usb.kicad_sch]
2026-07-24 forgot input to ILIM
    [board.kicad_pcb, usb.kicad_sch]
2026-07-25 pre accidentally messed up the references
    [audio.kicad_sch, board.kicad_pcb, board.kicad_sch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]
2026-07-25 fix audio refs and also move almost every component to bottom layer
    [board.kicad_pcb]
2026-07-25 1v8 power plane
    [board.kicad_pcb]
2026-07-25 some clean
    [board.kicad_pcb]
2026-07-25 loose ends
    [board.kicad_pcb, board.kicad_sch, mcu.kicad_sch]
2026-07-25 swd swclk run
    [board.kicad_pcb, board.kicad_sch]
2026-07-25 finish swd, usb status, starting uart out and rp2350 remap?
    [board.kicad_pcb, board.kicad_sch, usb.kicad_sch]
2026-07-28 wire encoder sw 3/4 and some cleanup
    [board.kicad_pcb, board.kicad_sch, mcu.kicad_sch]
2026-07-30 rotate encoders
    [board.kicad_pcb]
2026-07-30 every component on back, some length matching
    [board.kicad_pcb]
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2026-07-30 fix key footprint and wip fix matrix
    [board.kicad_pcb]
2026-08-03 fixed all keycaps?
    [board.kicad_pcb]
2026-08-03 fillout LCSC and swap micro usb
    [audio.kicad_sch, board.kicad_pcb, board.kicad_sch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]
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2026-08-04 fix the silkscreens AGAIN!?????????? why are my commits getting overridden
    [board.kicad_pcb, mcu.kicad_sch]
2026-08-05 add back the holes?????????????????????????????????????
    [board.kicad_pcb]
2026-08-05 fix some ref and fix some 3d
    [board.kicad_pcb]
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2026-08-05 move stuff out of cm4 shadow
    [board.kicad_pcb]
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2026-08-05 move enc silkscreen hopfully final prod
    [board.kicad_pcb]
2026-08-05 m2 holes in top corners
    [board.kicad_pcb]
2026-08-05 use 2.54mm debug pins
    [board.kicad_pcb, board.kicad_sch]
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2026-11-01 hw2 (#119)
    * upload
    * 3v3out, delete usb, add leds, LDO
    * i2c pullup
    * some conns
    * use 1v8 audio LDO
    * giga test points
    * barrel jack and power conns
    * Add KiCad diff previews
    * Update Kiri action
    * Pin Kiri action to maintained @v2 (KiCad 10 image)
    v2.0.9 shipped the old KiCad 6 image, which cannot open the board's
    2026-era KiCad files. @v2 tracks the current kicad-cli-only image.
    * some fields
    * joystick cap and organization
    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

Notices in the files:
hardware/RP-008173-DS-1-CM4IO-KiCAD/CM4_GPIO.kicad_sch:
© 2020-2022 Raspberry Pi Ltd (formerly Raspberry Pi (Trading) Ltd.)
